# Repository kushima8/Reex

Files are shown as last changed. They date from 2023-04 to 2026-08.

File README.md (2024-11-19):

# Reex
Modular Split keyboards  
  





# Build Guide

## Reex56
[ビルドガイド（日本語）](Reex56/Documents/reex56_buildguide.md)  
https://cyberdeckarsenal.booth.pm/items/4951435  
https://shop.yushakobo.jp/products/7793  

## Reex67
[ビルドガイド（日本語）](Reex67/Documents/reex67_buildguide.md)  
https://cyberdeckarsenal.booth.pm/items/4951447  
https://shop.yushakobo.jp/products/7930  

## ReexMod
[ビルドガイド（日本語）](Mod/reexmod_buildguide.md)  
https://cyberdeckarsenal.booth.pm/items/5617509  
https://cyberdeckarsenal.booth.pm/items/4773963  

## Reex56Mod (Reex56 + ReexMod)
https://shop.yushakobo.jp/products/9454  

## Reex67Mod (Reex67 + ReexMod)
https://shop.yushakobo.jp/products/9455  

## Trackball Module ＆ Case
https://github.com/kushima8/PMW3360

120px-Cc-by-nc-sa_icon svg

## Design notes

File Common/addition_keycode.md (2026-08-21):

# Reex 追加キーコード一覧
 
Reexで使用できる独自キーコードの一覧です。  
RemapまたはVIAでキーに割り当ててご使用ください。  
  
## トラックボール
 
### 設定の保存・リセット
 
| キーコード | 説明 |
|---|---|
| `REC_RST` | センサー設定[^1]をリセット |
| `REC_SAVE` | 現在のセンサー設定[^1]をEEPROMに保存 |
 
### CPI（カーソル速度）
 
| キーコード | 説明 |
|---|---|
| `CPI_I100` | CPIを100増加（最大3500） |
| `CPI_D100` | CPIを100減少（最小100） |
| `CPI_I1K` | CPIを1000増加（最大3500） |
| `CPI_D1K` | CPIを1000減少（最小100） |
 
### スクロール
 
| キーコード | 説明 |
|---|---|
| `SCRL_TO` | 押すたびにスクロールモードのON/OFFを切り替え |
| `SCRL_MO` | 押している間だけスクロールモード |
| `SCRL_DVI` | スクロール除数を1つ上げる（最大 D7 = 1/128、最も遅い） |
| `SCRL_DVD` | スクロール除数を1つ下げる（最小 D0 = 1/1、最も速い） |
| `SSNP_VRT` | スクロールスナップを垂直方向に固定 |
| `SSNP_HOR` | スクロールスナップを水平方向に固定 |
| `SSNP_FRE` | スクロールスナップを無効化（自由スクロール） |
 
### 自動マウスレイヤー
 
| キーコード | 説明 |
|---|---|
| `AML_TO` | 自動マウスレイヤーのON/OFFを切り替え |
| `AML_I50` | 自動マウスレイヤーのタイムアウトを50ms増加（最大1000ms） |
| `AML_D50` | 自動マウスレイヤーのタイムアウトを50ms減少（最小100ms） |

#### 動作

自動マウスレイヤーのONの状態で、トラックボールを転がすと**レイヤー3**に自動で切り替わり、操作をやめてから設定時間（初期値650ms）が経過すると元のレイヤーに戻ります。  
レイヤー3にマウスボタンやスクロールを割り当てておくことで、レイヤー切り替えキーを押さずにマウス操作ができます。  

レイヤー3では、以下のキーがトラックボールを止めた状態でもレイヤーを維持します。  
マウス操作を続けるためのキーとして扱われるためです。  

- マウスボタン（`KC_BTN1`〜`KC_BTN8`）
- `SCRL_MO`
- 修飾キー（Ctrl / Shift / Alt / GUI）

上記以外のキーを割り当てた場合、押した時点でレイヤー3が解除され、下のレイヤーのキーが入力されます（トラックボールを動かしながら押した場合はレイヤー3のキーが入力されます）。  
そのため、レイヤー3には上記のキーを割り当てることを推奨します。  

なお、キーを押した直後の約200msはトラックボールを動かしてもレイヤーが切り替わりません。  
タイピング中に手が触れてしまった際の誤動作を防ぐための仕様です。  
 
[^1]: CPI、スクロール除数、自動マウスレイヤーのON/OFF状態、および自動マウスレイヤーのタイムアウト

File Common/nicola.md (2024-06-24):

| Code(hex) | Remap上での表記 | 説明 |
|----|:---:|----|
|0x7E40|User 0|NICOLA配列 1|
|0x7E41|User 1|NICOLA配列 2|
|0x7E42|User 2|NICOLA配列 3|
|0x7E43|User 3|NICOLA配列 4|
|0x7E44|User 4|NICOLA配列 5|
|0x7E45|User 5|NICOLA配列 6|
|0x7E46|User 6|NICOLA配列 7|
|0x7E47|User 7|NICOLA配列 8|
|0x7E48|User 8|NICOLA配列 9|
|0x7E49|User 9|NICOLA配列 0|
|0x7E4A|User 10|NICOLA配列 -|
|0x7E4B|User 11|NICOLA配列 =|
|0x7E4C|User 12|NICOLA配列 \|
|0x7E4D|User 13|NICOLA配列 Q|
|0x7E4E|User 14|NICOLA配列 W|
|0x7E4F|User 15|NICOLA配列 E|
|0x7E50|User 16|NICOLA配列 R|
|0x7E51|User 17|NICOLA配列 T|
|0x7E52|User 18|NICOLA配列 Y|
|0x7E53|User 19|NICOLA配列 U|
|0x7E54|User 20|NICOLA配列 I|
|0x7E55|User 21|NICOLA配列 O|
|0x7E56|User 22|NICOLA配列 P|
|0x7E57|User 23|NICOLA配列 [|
|0x7E58|User 24|NICOLA配列 ]|
|0x7E59|User 25|NICOLA配列 A|
|0x7E5A|User 26|NICOLA配列 S|
|0x7E5B|User 27|NICOLA配列 D|
|0x7E5C|User 28|NICOLA配列 F|
|0x7E5D|User 29|NICOLA配列 G|
|0x7E5E|User 30|NICOLA配列 H|
|0x7E5F|User 31|NICOLA配列 J|
|0x7E60|Any 0x7E60|NICOLA配列 K|
|0x7E61|Any 0x7E61|NICOLA配列 L|
|0x7E62|Any 0x7E62|NICOLA配列 ;|
|0x7E63|Any 0x7E63|NICOLA配列 '|
|0x7E64|Any 0x7E64|NICOLA配列 Z|
|0x7E65|Any 0x7E65|NICOLA配列 X|
|0x7E66|Any 0x7E66|NICOLA配列 C|
|0x7E67|Any 0x7E67|NICOLA配列 V|
|0x7E68|Any 0x7E68|NICOLA配列 B|
|0x7E69|Any 0x7E69|NICOLA配列 N|
|0x7E6A|Any 0x7E6A|NICOLA配列 M|
|0x7E6B|Any 0x7E6B|NICOLA配列 ,|
|0x7E6C|Any 0x7E6C|NICOLA配列 .|
|0x7E6D|Any 0x7E6D|NICOLA配列 /|
|0x7E6E|Any 0x7E6E|NICOLA配列 親指左|
|0x7E6F|Any 0x7E6F|NICOLA配列 親指右|
|0x7E70|Any 0x7E6F|NICOLA配列レイヤーに移動|TO（）やMO（）などのレイヤー移動コマンドではなくコチラを使用
|0x7E71|Any 0x7E6F|QWERTY配列レイヤーに移動|TO（）やMO（）などのレイヤー移動コマンドではなくコチラを使用

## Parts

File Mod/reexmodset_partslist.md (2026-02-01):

# ReexModセットパーツリスト

## はじめに
こちらはBoothなどで頒布しているReexModセット用の同梱部品一覧です。  
各拡張の組み立て方法や別途必要なものに関しては下記各ビルドガイドを参照してください。  

[①５キー拡張](5keymod_buildguide.md)  
[②３キー拡張](3keymod_buildguide.md)  
[③ロータリーエンコーダ拡張](rotaryencodermod_buildguide.md)  
[④１キー拡張](1keymod_buildguide.md)  
[⑤４キー拡張](4keymod_buildguide.md)  

## 部品
|名称|数量|備考|
|----|:---:|----|
|PCB|5枚|各種拡張基盤
|3キー拡張用スペーサー|1個|ネジ穴2つの細長いもの
|5キー拡張用スペーサー|1個|ネジ穴4つの細長いもの
|ロータリーエンコーダ拡張中央上部/下部用スペーサー|2個|両端穴付きバー形状のもの
|ロータリーエンコーダ拡張下段用スペーサー|1個|両端穴付きバー形状の円柱が高いもの
|ロータリーエンコーダ拡張基盤上部用スペーサー|1個|中央に凹みがある枠形状のもの
|M2 3.5mmスペーサー(ARB-2003.5E)|4個|丸型両メネジ|
|M2 6mmスペーサー(ARB-2006E)|4個|丸型両メネジ|
|M2 7.5mmスペーサー(ARB-2007.5E)|5個|丸型両メネジ|
|M2 11mmスペーサー(ARB-20011E)|8個|丸型両メネジ|
|M2 4mmネジ|13本|
|M2 6mmネジ|4本|
|M2 10mmネジ|13本|
|Kailh PCB ソケット(Cherry MX用)|14個|
|ダイオード(1N4148W)|25個|

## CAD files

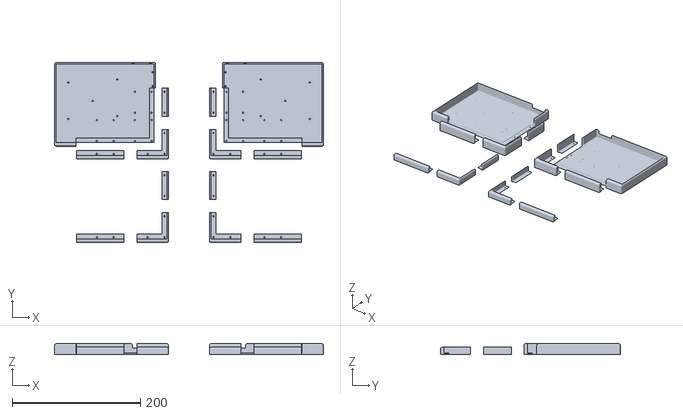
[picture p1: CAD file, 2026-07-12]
Reex56/Case/reex56_case.stl
419.6 x 280.6 x 16.5

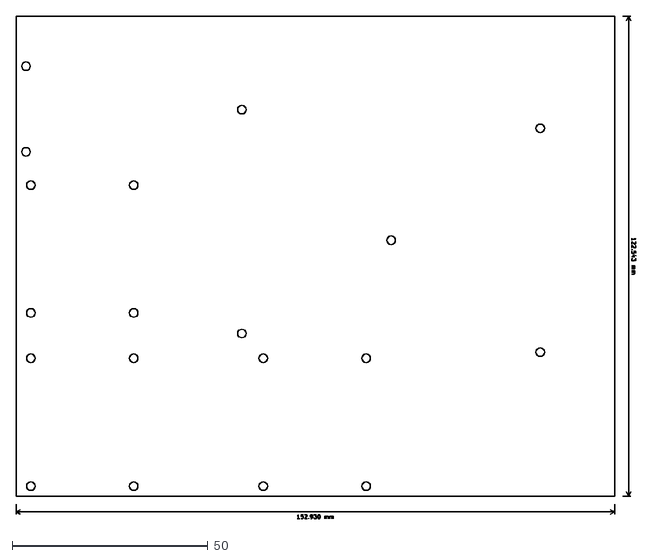
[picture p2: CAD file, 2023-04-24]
Reex56/Plate/reex56_b.dxf
158.3 x 128.3

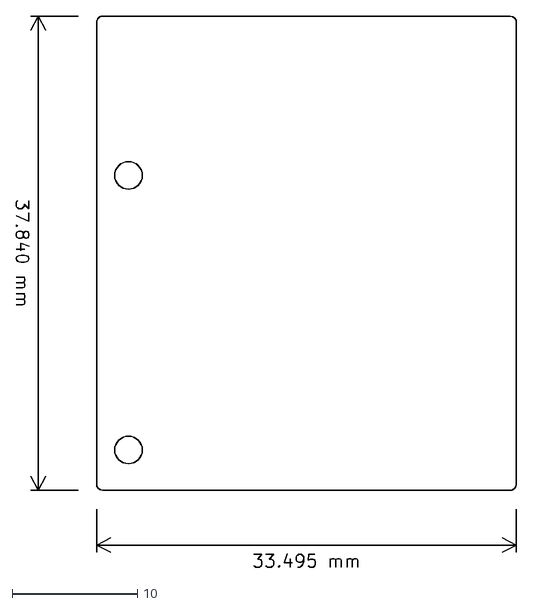
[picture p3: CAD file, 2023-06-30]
Reex67/Plate/reex_oledcover.dxf
39.9 x 44.0

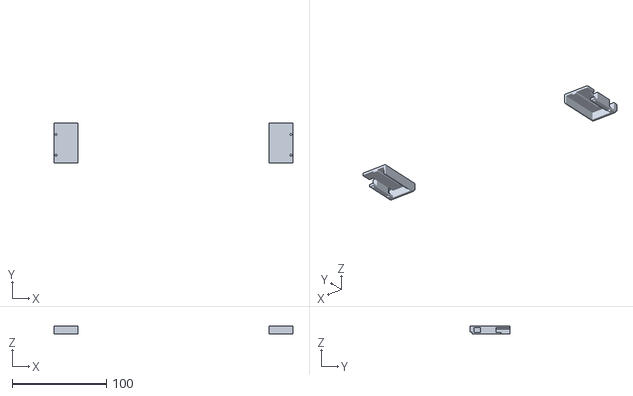
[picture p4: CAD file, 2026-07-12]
STL/reex_cover_3.5.stl
253.6 x 42.7 x 9.00

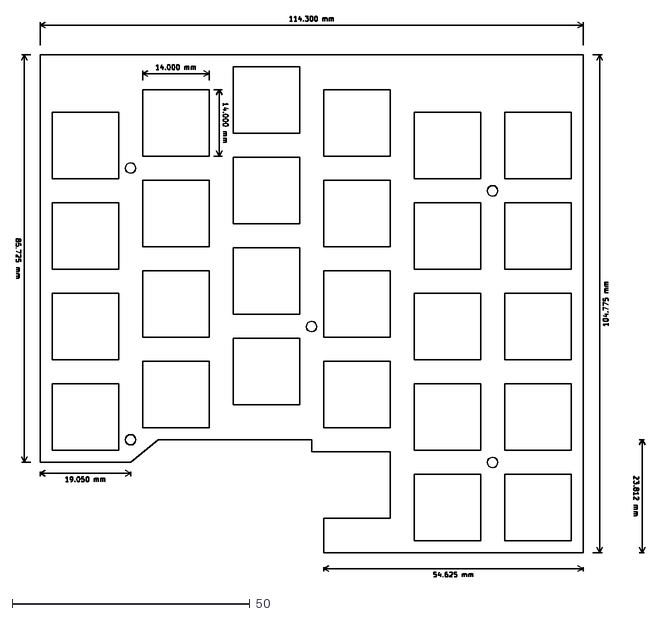
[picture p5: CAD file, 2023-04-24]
Reex56/Plate/reex56_t.dxf
132.4 x 118.1

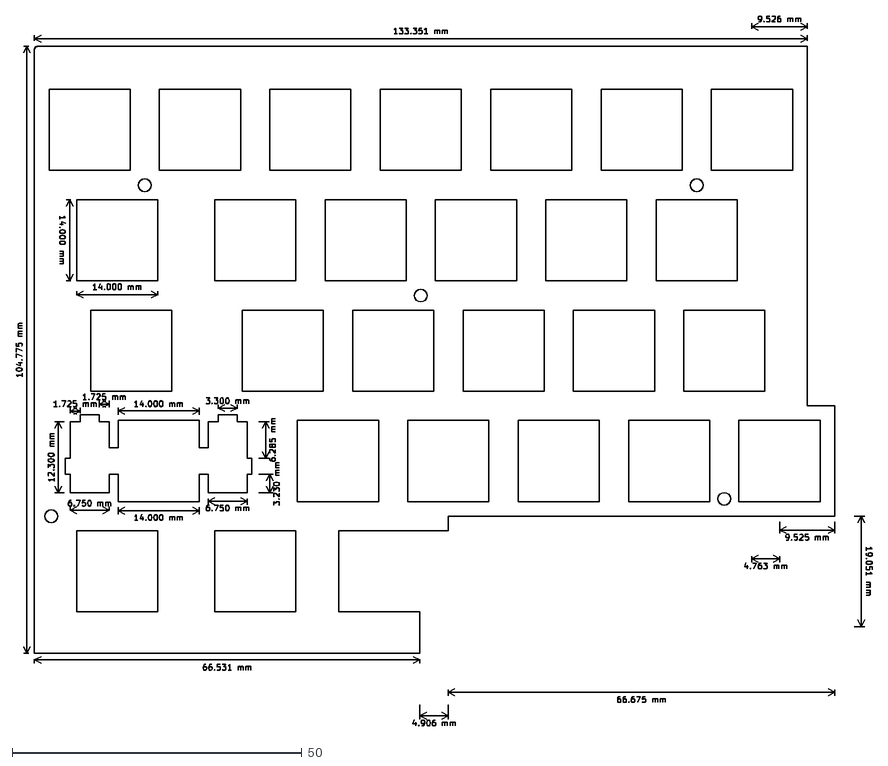
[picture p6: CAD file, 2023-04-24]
Reex67/Plate/reex67l_t.dxf
147.7 x 122.5

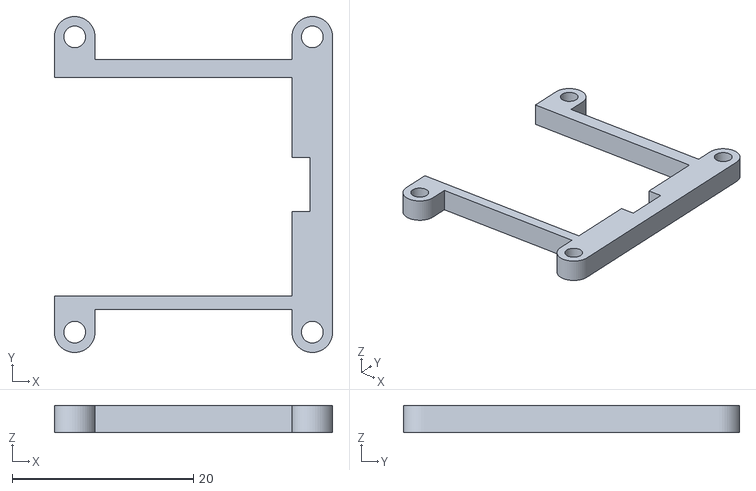
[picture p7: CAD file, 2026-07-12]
STL/reex_2.5_oneside_spacer.stl
30.7 x 37.1 x 3.00

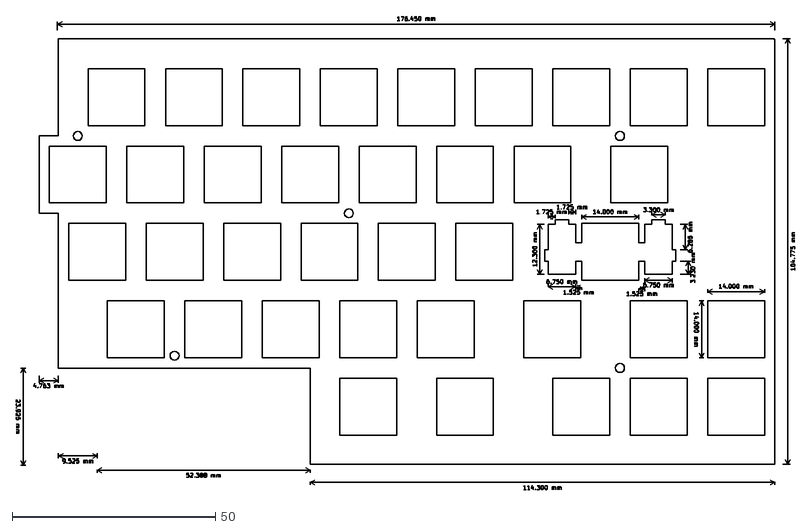
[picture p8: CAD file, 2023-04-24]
Reex67/Plate/reex67r_t.dxf
191.6 x 116.4

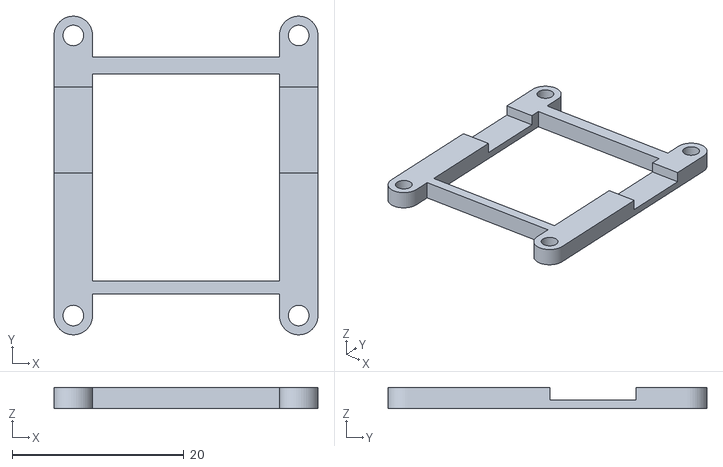
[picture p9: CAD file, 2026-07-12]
STL/reex_2.5_spacer.stl
30.7 x 37.1 x 2.50

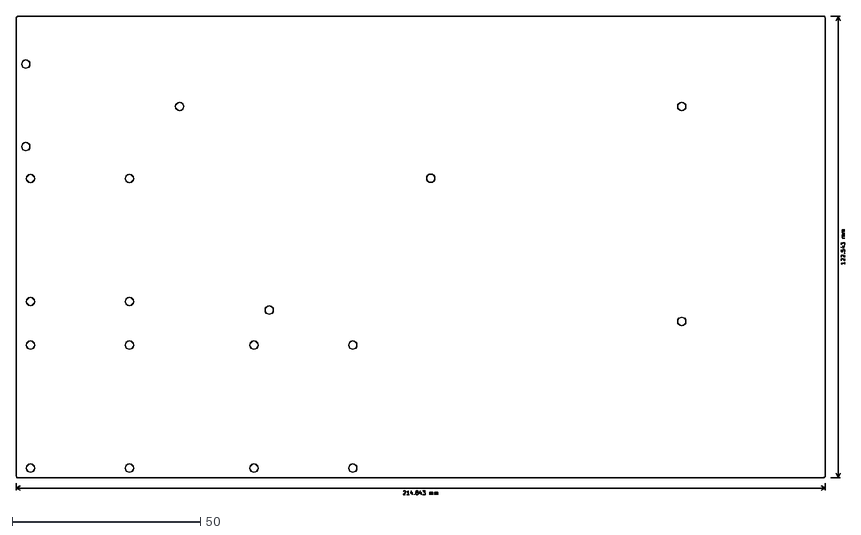
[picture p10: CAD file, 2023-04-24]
Reex67/Plate/reex67r_b.dxf
220.1 x 127.1

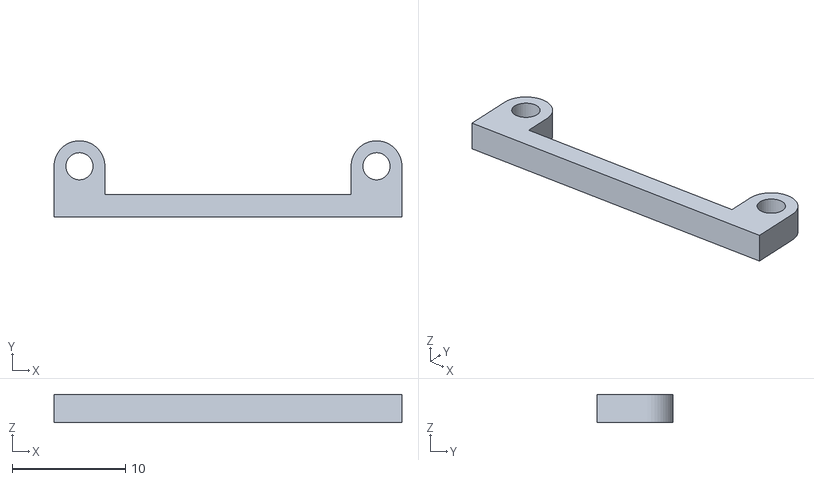
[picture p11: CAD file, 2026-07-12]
STL/reex_2.5_stick_spacer.stl
30.7 x 6.75 x 2.50

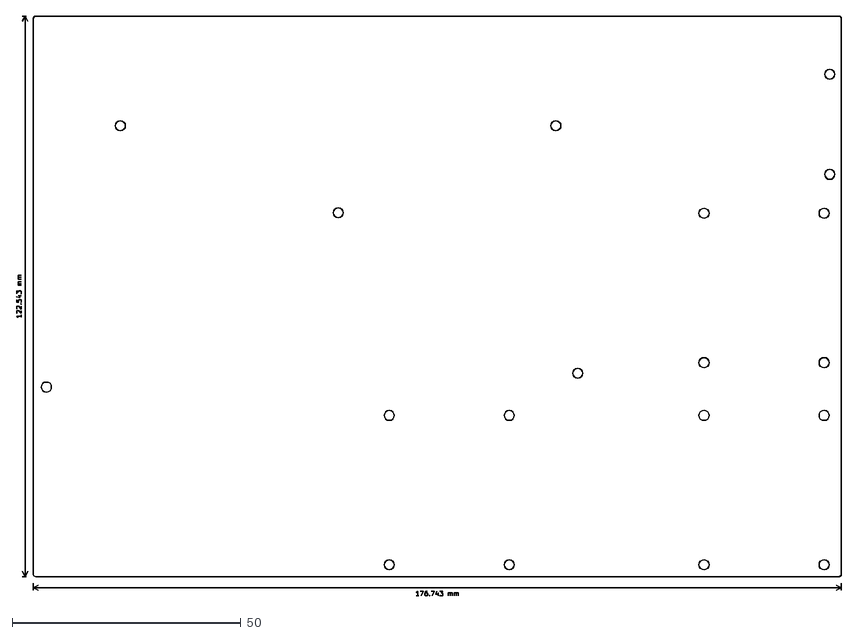
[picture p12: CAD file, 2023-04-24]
Reex67/Plate/reex67l_b.dxf
180.4 x 126.8

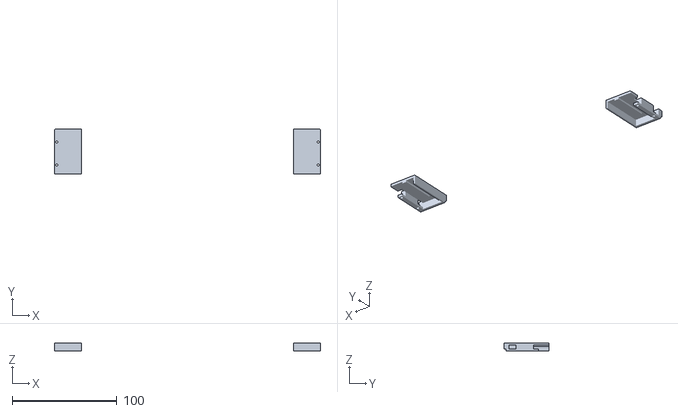
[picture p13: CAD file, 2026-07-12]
STL/reex_cover_2.5.stl
253.6 x 42.7 x 8.00

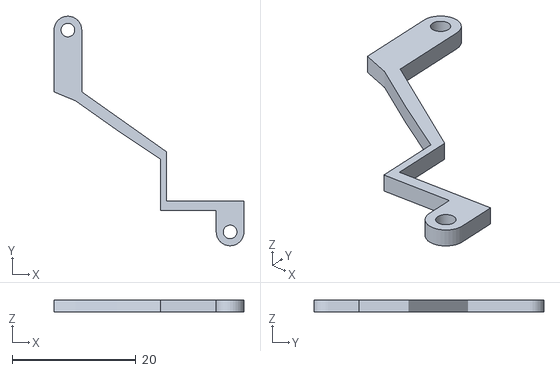
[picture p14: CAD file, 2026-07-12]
STL/reexmod_3key_spacer.stl
30.7 x 37.2 x 2.00

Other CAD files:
STL/reexmod_5key_spacer.stl
STL/reex_2.5-3.5_spacer.stl
STL/reex_cover_oled.stl
STL/reex_3.5_stick_spacer.stl

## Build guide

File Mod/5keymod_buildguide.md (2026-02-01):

# 5キー拡張 ビルドガイド

## はじめに
5キー拡張はReex56またはReex67の下記画像赤枠の位置へのみ取り付け可能です。  
※Reex67とReex56の差異はキースイッチ部分だけであり拡張取り付け部分は同一であるため、Reex67の画像は省略しております。  




キー拡張は同一側に一つのみ増設可能です。  
ロータリーエンコーダ拡張、トラックボール拡張との同一側での併用は可能です。  
（例：○ 右側 1キー拡張＋ロータリーエンコーダ拡張、左側 3キー拡張＋トラックボール拡張  
　　：✕ 右側 ロータリーエンコーダ拡張＋トラックボール拡張　左側 拡張なし   
　　：✕ 右側 拡張なし　左側  ロータリーエンコーダ拡張＋トラックボール拡張 ）  

## 部品

|名称|数量|備考|
|----|:---:|----|
|PCB|1枚|
|ボトムプレート|1枚|PCBと一体　捻って外せます|
|5キー拡張用スペーサー|1個|ネジ穴4つの細長いもの
|M2 7.5mmスペーサー(ARB-2007.5E)|3個|丸型両メネジ|
|M2 11mmスペーサー(ARB-20011E)|5個|丸型両メネジ|
|M2 4mmネジ|8本|
|M2 10mmネジ|8本|
|Kailh PCB ソケット(Cherry MX用)|5個|
|ダイオード(1N4148W)|8個|

### 別途、購入が必ず必要なもの
以下の部品は別途購入してください。

|名称|数量|備考|
|----|:---:|----|
|キースイッチ(Cherry MX互換)|5個|
|キースイッチ(Kailh Choc V1互換)|5個|Lofree Ghost switchも可|
|キーキャップ(Cherry MX互換)|5個|
|キーキャップ(Kailh Choc V1互換)|5個|
|電線|4本|
|スルーホール用テストワイヤ|4本|サンハヤト スルーホール用テストワイヤー TTW-200など|
|ゴム足|1個|

### オプション
以下の部品はオプション品です。 

|名称|数量|備考|
|----|:---:|----|
|Kailh PCB ソケット(Kailh Choc V1用)|5個|

## 組み立て
※拡張基板はリバーシブルPCBとなっております。  
　使用する位置とキーキャップの大きさにより実装面が変わります。  
　適宜説明内容を読み替えてご覧ください。 

* 1.7Pinコンスルー加工と差し替え
  * Reex基盤本体とトラックボール用センサーボードの接続に用いている8Pinコンスルーをニッパーなどを使い7Pinコンスルーに加工します。  
  * 8Pinコンスルーの右から三番目のPinをニッパーなどで切除してください。
  
  
  * Reex基盤本体の接続部分の右から三番目のPin（F6）に7PinコンスルーのPinが無くなっている部分が来るようにセンサボードと接続するようにしてください。
  
  
* 2.ファームウェアの書き込み
  * [reex56mod_default.hex](https://github.com/kushima8/Reex/tree/main/Reex56/HEX/mod/reex56mod_default.hex) or [reex67mod_default.hex](https://github.com/kushima8/Reex/tree/main/Reex67/HEX/mod/reex56mod_default.hex)を指定してファームウェアを書き込んでください。
* 3.ダイオードのはんだ付け
  * PCB裏面のダイオード取り付け箇所の片側にあらかじめはんだを盛ります。  
  * その後、線が書いてある方を右(三角形の頂点の先に縦棒がある方)にセットします。
  * ダイオードをピンセットで持ちつつ、あらかじめはんだを盛った箇所をはんだごてで加熱して片側だけはんだ付けを行います。  
  * 片側のはんだ付けが完了後、もう片方もはんだ付けを行ってください。
* 4.Kailh PCB ソケット(Cherry MX用)/Kailh PCB ソケット(Kailh Choc V1用)のはんだ付け
  * PCB裏面のソケット取り付け箇所にあらかじめはんだを盛ります。  
  * 中央の穴に干渉しないようにソケットをPCB裏面に設置しはんだ付けを行ってください。  
* 5.本体への取り付け
  * Reex本体のボトムプレートを外します。  
  * 画像赤枠の部分に  
  　・拡張基盤  
  　・5キー拡張用スペーサー  
  　・Reex本体基盤  
  　・7.5mmスペーサー  
  となるようにセットし、上から10mmネジで固定してください。   
  その後青枠の部分に  
  　・拡張基盤  
  　・11mmスペーサー  
  となるようにセットし、上から10mmネジで固定してください。  
  ※Reex67左側の中央下部のみ取り付け箇所が異なります。  
  　赤枠ではなく橙枠と青枠ではなく緑枠に取り付けてください。  
     
  
  
* 6.疎通テスト
  * 拡張基盤とReex本体基盤をテストワイヤで繋いでください。
  * TTW-200であればスルーホールに差し込むだけで接続できます。
  * 接続箇所は拡張基盤の印字とReex本体基盤の拡張取り付け部位近くにある印字が合うようにしてください。
  * Reex本体基盤の複数同じ印字がありますが、どちらに刺しても問題ありません。
  * 配線に関しては下記が画像を参考にしてください。
     
  
  
  * 接続後、キースイッチを取り付け入力可能かテストを行ってください。
  * 問題なければボトムプレートを配置し、4mmネジで固定してください。
* 7.電線のはんだ付け
  * この工程を行うと拡張基盤の取り外しが困難になります。
  * テストワイヤで接続した状態で、十分操作感などを確かめ変更の余地がないと確認後、この工程に進むようにしてください。
  * テストワイヤを外し電線と入れ替えるような形で拡張基板と本体基盤にはんだ付けを行い接続してください。

組み立ての手順は、以上です。

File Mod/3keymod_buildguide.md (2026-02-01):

# 3キー拡張 ビルドガイド

## はじめに
3キー拡張はReex56またはReex67の下記画像赤枠の位置へのみ取り付け可能です。  
※Reex67とReex56の差異はキースイッチ部分だけであり拡張取り付け部分は同一であるため、Reex67の画像は省略しております。  
  



キー拡張は同一側に一つのみ増設可能です。  
ロータリーエンコーダ拡張、トラックボール拡張との同一側での併用は可能です。  
（例：○ 右側 1キー拡張＋ロータリーエンコーダ拡張、左側 3キー拡張＋トラックボール拡張  
　　：✕ 右側 ロータリーエンコーダ拡張＋トラックボール拡張　左側 拡張なし   
　　：✕ 右側 拡張なし　左側  ロータリーエンコーダ拡張＋トラックボール拡張 ）  

## 部品

|名称|数量|備考|
|----|:---:|----|
|PCB|1枚|
|ボトムプレート|1枚|PCBと一体　捻って外せます|
|3キー拡張用スペーサー|1個|ネジ穴2つの細長いもの
|M2 7.5mmスペーサー(ARB-2007.5E)|2個|丸型両メネジ|
|M2 11mmスペーサー(ARB-20011E)|3個|丸型両メネジ|
|M2 4mmネジ|5本|
|M2 10mmネジ|5本|
|Kailh PCB ソケット(Cherry MX用)|3個|
|ダイオード(1N4148W)|5個|

### 別途、購入が必ず必要なもの
以下の部品は別途購入してください。

|名称|数量|備考|
|----|:---:|----|
|キースイッチ(Cherry MX互換)|3個|
|キースイッチ(Kailh Choc V1互換)|3個|Lofree Ghost switchも可|
|キーキャップ(Cherry MX互換)|3個|
|キーキャップ(Kailh Choc V1互換)|3個|
|電線|4本|
|スルーホール用テストワイヤ|4本|サンハヤト スルーホール用テストワイヤー TTW-200など|
|ゴム足|1個|

### オプション
以下の部品はオプション品です。 

|名称|数量|備考|
|----|:---:|----|
|Kailh PCB ソケット(Kailh Choc V1用)|3個|

## 組み立て
※拡張基板はリバーシブルPCBとなっております。  
　使用する位置とキーキャップの大きさにより実装面が変わります。  
　適宜説明内容を読み替えてご覧ください。  

* 1.7Pinコンスルー加工と差し替え
  * Reex基盤本体とトラックボール用センサーボードの接続に用いている8Pinコンスルーをニッパーなどを使い7Pinコンスルーに加工します。  
  * 8Pinコンスルーの右から三番目のPinをニッパーなどで切除してください。
  
  
  * Reex基盤本体の接続部分の右から三番目のPin（F6）に7PinコンスルーのPinが無くなっている部分が来るようにセンサボードと接続するようにしてください。
  
  
* 2.ファームウェアの書き込み
  * [reex56mod_default.hex](https://github.com/kushima8/Reex/tree/main/Reex56/HEX/mod/reex56mod_default.hex) or [reex67mod_default.hex](https://github.com/kushima8/Reex/tree/main/Reex67/HEX/mod/reex56mod_default.hex)を指定してファームウェアを書き込んでください。
* 3.ダイオードのはんだ付け
  * PCB裏面のダイオード取り付け箇所の片側にあらかじめはんだを盛ります。  
  * その後、線が書いてある方を右(三角形の頂点の先に縦棒がある方)にセットします。
  * ダイオードをピンセットで持ちつつ、あらかじめはんだを盛った箇所をはんだごてで加熱して片側だけはんだ付けを行います。  
  * 片側のはんだ付けが完了後、もう片方もはんだ付けを行ってください。
* 4.Kailh PCB ソケット(Cherry MX用)/Kailh PCB ソケット(Kailh Choc V1用)のはんだ付け
  * PCB裏面のソケット取り付け箇所にあらかじめはんだを盛ります。  
  * 中央の穴に干渉しないようにソケットをPCB裏面に設置しはんだ付けを行ってください。  
* 5.本体への取り付け
  * Reex本体のボトムプレートを外します。  
  * 画像赤枠の部分に  
  　・拡張基盤  
  　・3キー拡張用スペーサー
  　・Reex本体基盤  
  　・7.5mmスペーサー  
  となるようにセットし、上から10mmネジで固定してください。  
  その後青枠の部分に  
  　・拡張基盤  
  　・11mmスペーサー  
  となるようにセットし、上から10mmネジで固定してください。  
     
  
  
* 6.疎通テスト
  * 拡張基盤とReex本体基盤をテストワイヤで繋いでください。
  * TTW-200であればスルーホールに差し込むだけで接続できます。
  * 接続箇所は拡張基盤の印字とReex本体基盤の拡張取り付け部位近くにある印字が合うようにしてください。
  * Reex本体基盤の複数同じ印字がありますが、どちらに刺しても問題ありません。
  * 配線に関しては下記が画像を参考にしてください。
     
  
  
  * 接続後、キースイッチを取り付け入力可能かテストを行ってください。
  * 問題なければボトムプレートを配置し、4mmネジで固定してください。
* 7.電線のはんだ付け
  * この工程を行うと拡張基盤の取り外しが困難になります。
  * テストワイヤで接続した状態で、十分操作感などを確かめ変更の余地がないと確認後、この工程に進むようにしてください。
  * テストワイヤを外し電線と入れ替えるような形で拡張基板と本体基盤にはんだ付けを行い接続してください。

組み立ての手順は、以上です。

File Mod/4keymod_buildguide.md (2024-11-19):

# 4キー拡張 ビルドガイド

## はじめに
4キー拡張はReex56またはReex67の下記画像赤枠の位置へのみ取り付け可能です。  
※Reex67とReex56の差異はキースイッチ部分だけであり拡張取り付け部分は同一であるため、Reex67の画像は省略しております。  
  


キー拡張は同一側に一つのみ増設可能です。  
ロータリーエンコーダ拡張、トラックボール拡張との同一側での併用は可能です。  
（例：○ 右側 1キー拡張＋ロータリーエンコーダ拡張、左側 3キー拡張＋トラックボール拡張  
　　：✕ 右側 ロータリーエンコーダ拡張＋トラックボール拡張　左側 拡張なし   
　　：✕ 右側 拡張なし　左側  ロータリーエンコーダ拡張＋トラックボール拡張 ）  

## 部品

|名称|数量|備考|
|----|:---:|----|
|PCB|1枚|
|ボトムプレート|1枚|PCBと一体　捻って外せます|
|M2 6mmスペーサー(ARB-2006E)|4個|丸型両メネジ|
|M2 4mmネジ|4本|
|M2 6mmネジ|4本|
|Kailh PCB ソケット(Cherry MX用)|4個|
|ダイオード(1N4148W)|7個|

### 別途、購入が必ず必要なもの
以下の部品は別途購入してください。

|名称|数量|備考|
|----|:---:|----|
|キースイッチ(Cherry MX互換)|4個|
|キースイッチ(Kailh Choc V1互換)|4個|Lofree Ghost switchも可|
|キーキャップ(Cherry MX互換)|4個|
|キーキャップ(Kailh Choc V1互換)|4個|
|電線|3本|
|スルーホール用テストワイヤ|3本|サンハヤト スルーホール用テストワイヤー TTW-200など|
|ゴム足|2個|

### オプション
以下の部品はオプション品です。 

|名称|数量|備考|
|----|:---:|----|
|Kailh PCB ソケット(Kailh Choc V1用)|4個|

## 組み立て

* 1.7Pinコンスルー加工と差し替え
  * Reex基盤本体とトラックボール用センサーボードの接続に用いている8Pinコンスルーをニッパーなどを使い7Pinコンスルーに加工します。  
  * 8Pinコンスルーの右から三番目のPinをニッパーなどで切除してください。
  
  
  * Reex基盤本体の接続部分の右から三番目のPin（F6）に7PinコンスルーのPinが無くなっている部分が来るようにセンサボードと接続するようにしてください。
  
  
* 2.ファームウェアの書き込み
  * [reex56mod_default.hex](https://github.com/kushima8/Reex/tree/main/Reex56/HEX/mod/reex56mod_default.hex) or [reex67mod_default.hex](https://github.com/kushima8/Reex/tree/main/Reex67/HEX/mod/reex56mod_default.hex)を指定してファームウェアを書き込んでください。
* 3.ダイオードのはんだ付け
  * PCB裏面のダイオード取り付け箇所の片側にあらかじめはんだを盛ります。  
  * その後、線が書いてある方を右(三角形の頂点の先に縦棒がある方)にセットします。
  * ダイオードをピンセットで持ちつつ、あらかじめはんだを盛った箇所をはんだごてで加熱して片側だけはんだ付けを行います。  
  * 片側のはんだ付けが完了後、もう片方もはんだ付けを行ってください。
* 4.Kailh PCB ソケット(Cherry MX用)/Kailh PCB ソケット(Kailh Choc V1用)のはんだ付け
  * PCB裏面のソケット取り付け箇所にあらかじめはんだを盛ります。  
  * 中央の穴に干渉しないようにソケットをPCB裏面に設置しはんだ付けを行ってください。  
* 5.本体への取り付け
  * Reex本体のボトムプレートを外します。  
  * 画像赤枠の部分に  
  　・Reex本体基盤  
  　・拡張基盤  
  　・6mmスペーサー  
  となるようにセットし、上から6mmネジで固定してください。  
    
  
  
  その後拡張基盤下部に  
  　・拡張基盤  
  　・6mmスペーサー  
  となるようにセットし、上から6mmネジで固定してください。  
* 6.疎通テスト
  * 拡張基盤とReex本体基盤をテストワイヤで繋いでください。
  * TTW-200であればスルーホールに差し込むだけで接続できます。
  * 接続箇所は拡張基盤の印字とReex本体基盤の拡張取り付け部位近くにある印字が合うようにしてください。
  * Reex本体基盤の複数同じ印字がありますが、どちらに刺しても問題ありません。
  * 配線に関しては下記が画像を参考にしてください。  
    
  
  
  * 接続後、キースイッチを取り付け入力可能かテストを行ってください。
  * 問題なければボトムプレートを配置し、4mmネジで固定してください。
* 7.電線のはんだ付け
  * この工程を行うと拡張基盤の取り外しが困難になります。
  * テストワイヤで接続した状態で、十分操作感などを確かめ変更の余地がないと確認後、この工程に進むようにしてください。
  * テストワイヤを外し電線と入れ替えるような形で拡張基板と本体基盤にはんだ付けを行い接続してください。

組み立ての手順は、以上です。

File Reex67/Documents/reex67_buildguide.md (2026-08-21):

# Reex67 ビルドガイド

## ご購入前にお読みください

本製品をご購入いただいた時点で、下記「譲渡・再販について」の内容にご同意いただいたものとみなします。

### 譲渡・再販について

BOOTHや遊舎工房など、作者本人が販売または委託している場所以外で購入された場合、同梱品の不足や不良品への対応など、各種サポートをいたしかねます。  
そのため、以下のとおりお願いしております。

1. 本製品（完成品・未完成品・付属部品を問わず）を、ネットオークション、フリマサービス、その他の方法により第三者へ有償で譲渡することを禁止します。
2. 本項に反する行為を確認した場合、以後の販売をお断りする場合があります。

## はじめに


このたびはご購入いただきありがとうございます。  
本製品は組み立てが必要なキットです。  

作成にあたり不明点や疑問点などがありましたら、作者の[Twitterアカウント](https://twitter.com/kushima8)までご連絡ください。  
Twitter以外で連絡を頂いても対応が厳しいです。  
FF外からのリプライは通知オフにしており気づかない場合がこざいますご了承ください。  
それとDiscordのコミュニティなどで作者以外の方だけに不明点や疑問点などを質問することは非推奨です。  

Reex67は各種ブレークアウトボードを接続して拡張することを主眼に開発したモジュラー式キーボードです。  
使用するキーキャップについては[キーレイアウト](https://www.keyboard-layout-editor.com/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'&_w:2.25%3B&=Enter%3B&@_w:2.25%3B&=Shift&=Z&=X&=C&=V&=B&_x:3.75%3B&=N&=M&=%3C%0A,&=%3E%0A.&=%3F%0A%2F%2F&_w:1.75%3B&=Shift&=%E2%86%91&=Fn%3B&@_w:1.5%3B&=Ctrl&=Fn&_w:1.25%3B&=GUI&_x:2&w:1.5%3B&=Space&_x:3&w:1.25%3B&=Space&_x:2.25&w:1.5%3B&=GUI&=ALT&_x:0.5%3B&=%E2%86%90&=%E2%86%93&=%E2%86%92)を確認してください。  

写真は作成見本であり商品内容と同一ではありません。  
また仕様は予告なく変更されることがあります。  

完成品、未完成品にかかわらずヤフオク!やメルカリなどのネットオークションやフリマなどでの販売、転売は禁止しております。  
Boothや遊舎工房など作者本人が販売または委託している箇所以外で購入された場合、同梱品の不足や不良品の対応などの各種サポートが厳しいためです。  
もし発見した場合は対応します。  
ご理解のほどよろしくお願いいたします。  

ファームウェアに[qmk_firmware](https://github.com/qmk/qmk_firmware)を採用しています。  
QMKにReex67のコードはまだマージされていませんのでこの[ブランチ](https://github.com/kushima8/qmk_firmware/tree/reex)を使用してください。  

キット作成前にPro Microの書き込み環境の構築を行ってください。  
ファームウェアの書き込み環境の構築については下記のサリチル酸さんのサイトを参考にしてください。  
[（初心者編）自作キーボードにファームウェアを書き込む](https://salicylic-acid3.hatenablog.com/entry/qmk-toolbox)  

キー割り当ての変更方法などはご自身でお調べいただくようお願いします。  

GUIから簡単にキー割り当てを変更できる[VIA](https://caniusevia.com/)と[Remap](https://remap-keys.app/)に対応しております。  
各種キー割り当ても含めLEDの光度などの設定できますのでご活用ください。  
VIAとRemapについては下記のサリチル酸さんのサイトを参考にしてください。  
[（初心者編）VIAを使ってキーマップを書き換えよう](https://salicylic-acid3.hatenablog.com/entry/via-manual)  
[（初心者編）Remapを使ってキーマップを書き換えよう](https://salicylic-acid3.hatenablog.com/entry/remap-manual)  

[プレートデータ](https://github.com/kushima8/Reex/tree/main/Reex67/Plate)データを公開しています。  
アルミプレートなど作成したい場合にお使いください。  

[センサブレイクアウトボート](https://github.com/kushima8/PMW3360)に関してもケース含めデータを公開しています。  
ご自由にお使いください。  

以下の部品リストを参考に欠品がないか確認をお願いします。  
欠品や不良品などがありましたら確認したのちに対応いたします。  
ただし、海外など発送が難しい場合はこちらの指定する方法での一部返金などで対応します。  
あらかじめご了承ください。  

## 部品

### キットに付属しているもの

|名称|数量|備考|
|----|:---:|----|
|PCB|2枚|右側用、左側用各1枚ずつ|
|トッププレート|2枚|右側用、左側用各1枚ずつ|
|ボトムプレート|2枚|右側用、左側用各1枚ずつ|
|スペースキー用トッププレート|2枚||
|中央上部/下部用スペーサー|1個||枠形状のもの
|下段用スペーサー|1個|片側の円柱が高い枠形状のもの|
|M2 3mmスペーサー(ARB-2003E)|10個|丸型両メネジ|
|M2 3.5mmスペーサー(ARB-2003.5E)|4個|丸型両メネジ|
|M2 7.5mmスペーサー(ARB-2007.5E)|10個|丸型両メネジ|
|M2 4mmネジ|14本|
|M2 10mmネジ|14本|
|Kailh PCB ソケット(MX用)|69個|
|ダイオード(1N4148W)|86個|
|タクトスイッチ|2個|
|TRRSジャック(MJ-4PP-9)|2個|
|PMW3360DM-T2QU|1個|レンズ付き|
|PMW3360ブレイクアウトボード|1枚|
|34mm版トラックボールケース|1個|ローマウント版|
|25mm版トラックボールケースカバー(右側用) |1個||
|25mm版トラックボールケースカバー(左側用） |1個||
|ステンレスミニアチュアベアリング(3×6×2.5mm)|3個|
|六角ナット(M3 厚さ2.4mm)|3個|
|(+)ナベ頭小ねじ(M3 10mm)|3個|
|コンスルーピンヘッダ(2.5mm 8PIN)|1個|
|ゴム足|8個|

### 別途、購入が必ず必要なもの
以下の部品は別途購入してください。

|名称|数量|備考|
|----|:---:|----|
|キースイッチ(Cherry MX互換)|67個|
|キーキャップ(Cherry MX互換)|67個|
|Pro Micro|2個|※|
|コンスルーピンヘッダ(2.5mm 12PIN)|4個|
|TRRSケーブル|1本|
|トラックボール(34mm)|1個|
|2Uスタビライザー(Cherry MX互換)|2個|

※動作確認しているPro Microは以下の通りになります。  
　下記以外のPro Microを使用する場合は動作しないことがあります。  
　使用する場合はご自身で調整してください。  
　Pro Micro（単体）黒基盤/青基盤  
　https://shop.yushakobo.jp/products/pro-micro?variant=42225070768359

### オプション
以下の部品はオプション品です。  
キーボードを光らせたいなどの場合のみ別途購入してください。  

|名称|数量|備考|
|----|:---:|----|
|LEDチップ(YS-SK6812MINI-E)|75個|
|OLEDモジュール|2個|
|OLED用ピンソケット|2個|

※一部画像に制作手順が似ているReex56の画像を使用しております。

## 組み立て
* 表面  
  
* 裏面  
  
* 1.ヤスリがけ
  * 製造の都合上PCBにバリが存在します。  
  
  * 赤丸の箇所を市販されている紙ヤスリなどで研磨してください。
* 2.Pro Microのはんだ付け
  * チップが載っている面が内側になるようにし、コンスルーピンヘッダを取り付けはんだ付けをしてください。
  * コンスルーピンヘッダには取り付け方向があるため気をつけてください。
  * [コンスルー - Self-Made Keyboards in Japan - ](https://scrapbox.io/self-made-kbds-ja/%E3%82%B3%E3%83%B3%E3%82%B9%E3%83%AB%E3%83%BC)  
  
* 3.ファームウェアの書き込み
  * [reex67_test.hex](https://github.com/kushima8/Reex/tree/main/Reex67/HEX/reex67_test.hex)を指定してファームウェアを書き込んでください。
* 4.センサーのはんだ付け
  * ブレイクアウトボードの既にICがはんだ付けされている⾯を表にし、4PINが2列になっている方を左側してください。
  * センサーチップの⽂字が書かれている⽅を下にしてブレイクアウトボードにセットしたあと、裏面からはんだ付けをしてください。
  * はんだ付けが終わったらセンサに貼られているシールを剥がしてください。  
 
  * レンズのガイドポストを変形させることで、レンズをセンサに固定できます。  
  * 固定する場合は一度本機を完成させトラックボールが動くことを確認したのち、レンズをセンサにキッチリはめ込んだ状態ではんだごてなどを使い画像赤丸部分のガイドポストをセンサに触れないように溶かし変形させ固定してください。  
  * 高温すぎるとガイドポスト溶けすぎてしまうので、はんだごでなのでネジを熱し、熱したネジをガイドポストに押し付けるなどで変形させるとうまくいきます。  
 
* 5.トラックボールケースの作成  
  * 本キットでは34mm版ケースと25mm版ケースを同梱しております。  
  * 組み立て組み込み方はどちらも同じ手順で可能です。  
  * ご自身でお好きなものを選んで組み込んでください。  
  * [ケースデータ](https://github.com/kushima8/PMW3360/tree/main/stl)は公開中ですのでご自由にお使いください。
    
  * ケースは突起が突き出ているほうが表側であり、突起が2つある⽅が上、突起が1つの方が下となります。  
  * 初めに上側のネジ⽳にM2 10mmネジを⼀つづ⼊れます  
  * その後ベアリングを取り付けたM3 10mmネジを突起の穴ねじ込みます。  
  * 入れる方向などは下記画像を参考にしてください。  
  * 設置後、六角ナットで固定。  
  * 固定する際突起部分とベアリング部分を完全に密着せず若干ながら隙間を作るようにしてください。  
  * 密着しすぎるとベアリングがうまく回らない場合があります。  
    
  * 一旦この状態でトラックボールを置き、干渉の確認をしてください。  
  * ケース本体は3Dプリンタで製造しており、個体差によっては玉と爪が干渉する場合があります。  
  * 干渉する場合、、干渉しない用にヤスリなどで加工してください。  
* 6.LEDチップのはんだ付け(オプション)
  * 高い温度ではんだ付けを行うとLED破損の可能性がありますので、約270℃に設定してはんだ付けをするようにしてください。
  * 基板裏面のL字のシルクのマークの位置にLEDの足が欠けている箇所が来るように設置し、はんだ付けを行ってください。
  * はんだ付けが完了したら一度Pro Microを取り付け、LEDが光るかどうかテストを行ってください。  
  
* 7.ダイオードのはんだ付け
  * PCB裏面のダイオード取り付け箇所の片側にあらかじめはんだを盛ります。  
  
  * その後、線が書いてある方を右(三角形の頂点の先に縦棒がある方)にセットします。
  * ダイオードをピンセットで持ちつつ、あらかじめはんだを盛った箇所をはんだごてで加熱して片側だけはんだ付けを行います。  
  
  * 片側のはんだ付けが完了後、もう片方もはんだ付けを行ってください。
* 8.Kailh PCB ソケット(MX用)のはんだ付け
  * PCB裏面のソケット取り付け箇所にあらかじめはんだを盛ります。  
  
  * 中央の穴に干渉しないようにソケットをPCB裏面に設置しはんだ付けを行ってください。  
  
* 9.タクトスイッチはんだ付け
  * PCB表面から取り付け、裏面からはんだ付けを行ってください。
* 10.TRRSジャックのはんだ付け
  * PCB表面から取り付け、裏面からはんだ付けを行ってください。
* 11.OLEDの取り付け(オプション)
  * OLEDモジュールとピンヘッダのハンダ付けを行ってください。
  * ピンソケットをPCB表面から取り付け、裏面からはんだ付けを行ってください。
* 12.トラックボールユニットの取り付け  
  * トラックボールユニットは画像赤丸の六箇所から選択が可能です。  
    
  * 中央上部と中央下部の場合は12.1を、下段の場合は12.2を参考に取り付けてください。  
    * 12.1 中央上部と中央下部取り付け  
    * ケース下側のネジ⽳にM2 10mmネジを⼀つづ⼊れてください。  
    * PCB上面にケースを配置してください。  
      
    * PCB裏側からコンスルーを取り付け、ネジに中央上部/下部用スペーサーを取り付けてください。  
      
    * その後ブレイクアウトボードを取り付け、M2 3.5mmスペーサーを設置してください。  
      
    * 12.2 下段取り付け  
    * ケース下側のネジ⽳にM2 10mmネジを⼀つづ⼊れてください。  
    * PCB上面にケースを配置してください。  
    * PCB裏側からコンスルーを取り付け、ネジに下部用スペーサーを通してください。  
      
    * その後ブレイクアウトボードを取り付け、M2 3.5mmスペーサーを設置してください。  
      
* 13.キースイッチの取り付け
  * トッププレートの穴にキースイッチを取り付けてください。  
  
* 14.トッププレートの取り付け
  * トッププレート上面のネジ穴からM2 10mmネジを通し、M2 3mmスペーサーで固定してください。
  * PCBとネジ穴とキースイッチが合うようにトッププレートをPCB表面に設置。
  * 設置後、PCB裏面に飛び出たネジにM2 7.5mmスペーサーを取り付けてください。  
  
* 15.ボトムプレートの取り付け。
  * スペーサーとボトムプレートのネジ穴の位置を合わせ、M2 4mmネジで固定してください。  
* 16.Pro Microの取り付け
  * Pro Microを取り付け、PCと接続しREMAPなどを用いてキースイッチの入力の確認を行ってください。
* 17.OLEDモジュールの取り付け(オプション)
  * OLEDモジュールを取り付け、PCと接続し、表示されることの確認を行ってください。
* 18.キーキャップの取り付け
  * キースイッチにキーキャップを取り付けてください。
* 19.ゴム足の取り付け
  * ボトムプレートにゴム足を取り付けください。

組み立ての手順は、以上です。

### 用意しているファームウェアについて
3種類ほどこちらにてコンパイル済みの[ファームウェア](https://github.com/kushima8/Reex/tree/main/Reex67/HEX)を用意しております。  
中身についてはこちらの[QMK](https://github.com/kushima8/qmk_firmware/tree/reex)にて確認してください。  
以下簡単な説明になります。  
独自追加キーコードに関しては[addition_keycode](https://github.com/kushima8/Reex/tree/main/Common/addition_keycode.md)にて確認してください。  
  
* reex67_default.hex
  * [VIA対応(Remap)](https://github.com/kushima8/Reex/tree/main/Reex67/VIA)
  * レイヤー4枚
  * １番レイヤーのみボールを一定動かすと3番レイヤー(マウスレイヤー)に自動遷移  
    ボールを停止して一定時間経過か、LCTRLと設定したマウスキーやスクロールキー以外を押下すると遷移前レイヤーに戻る
* reex67_12k.hex
  * [VIA対応(Remap)](https://github.com/kushima8/Reex/tree/main/Reex56/VIA)
  * レイヤー4枚
  * １番レイヤーのみボールを一定動かすと3番レイヤー(マウスレイヤー)に自動遷移  
    ボールを停止して一定時間経過か、LCTRLと設定したマウスキーやスクロールキー以外を押下すると遷移前レイヤーに戻る
  * MAXCPI 12000（他ファームウェアはMAPCPI 3500）
  * ワンショットキー機能、タッピング機能無効
* reex67_test.hex
  * 動作確認用
  * [VIA対応(Remap)](https://github.com/kushima8/Reex/tree/main/Reex67/VIA)
  * レイヤー1枚

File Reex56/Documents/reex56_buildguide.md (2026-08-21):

# Reex56 ビルドガイド

## ご購入前にお読みください

本製品をご購入いただいた時点で、下記「譲渡・再販について」の内容にご同意いただいたものとみなします。

### 譲渡・再販について

BOOTHや遊舎工房など、作者本人が販売または委託している場所以外で購入された場合、同梱品の不足や不良品への対応など、各種サポートをいたしかねます。  
そのため、以下のとおりお願いしております。

1. 本製品（完成品・未完成品・付属部品を問わず）を、ネットオークション、フリマサービス、その他の方法により第三者へ有償で譲渡することを禁止します。
2. 本項に反する行為を確認した場合、以後の販売をお断りする場合があります。

## はじめに


このたびはご購入いただきありがとうございます。  
本製品は組み立てが必要なキットです。  

作成にあたり不明点や疑問点などがありましたら、作者の[Twitterアカウント](https://twitter.com/kushima8)までご連絡ください。  
Twitter以外で連絡を頂いても対応が厳しいです。  
FF外からのリプライは通知オフにしており気づかない場合がこざいますご了承ください。  
それとDiscordのコミュニティなどで作者以外の方だけに不明点や疑問点などを質問することは非推奨です。  

Reex56は各種ブレークアウトボードを接続して拡張することを主眼に開発したモジュラー式キーボードです。  
使用するキーキャップについては[キーレイアウト](https://www.keyboard-layout-editor.com/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(%0A9%3B&@_y:-0.8799999999999999&x:5%3B&=%25%0A5&_x:0.75%3B&=%5E%0A6%3B&@_y:-0.875&a:7%3B&=%3B&@_y:-0.995&x:1&a:4%3B&=!%0A1&_x:8.75%3B&=)%0A0&_a:7%3B&=%3B&@_y:-0.3799999999999999&x:3&a:4%3B&=E&_x:4.75%3B&=I%3B&@_y:-0.8700000000000001&x:2%3B&=W&_x:1%3B&=R&_x:2.75%3B&=U&_x:1%3B&=O%3B&@_y:-0.8799999999999999&x:5%3B&=T&_x:0.75%3B&=Y%3B&@_y:-0.875&a:7%3B&=%3B&@_y:-0.9950000000000001&x:1&a:4%3B&=Q&_x:8.75%3B&=P&_a:7%3B&=%3B&@_y:-0.3799999999999999&x:3&a:4%3B&=D&_x:4.75%3B&=K%3B&@_y:-0.8700000000000001&x:2%3B&=S&_x:1%3B&=F&_x:2.75%3B&=J&_x:1%3B&=L%3B&@_y:-0.8799999999999999&x:5%3B&=G&_x:0.75%3B&=H%3B&@_y:-0.875&a:7%3B&=%3B&@_y:-0.9950000000000001&x:1&a:4%3B&=A&_x:8.75%3B&=%2F:%0A%2F%3B&_a:7%3B&=%3B&@_y:-0.3799999999999999&x:3&a:4%3B&=C&_x:4.75%3B&=%3C%0A,%3B&@_y:-0.8700000000000001&x:2%3B&=X&_x:1%3B&=V&_x:2.75%3B&=M&_x:1%3B&=%3E%0A.%3B&@_y:-0.8799999999999999&x:5%3B&=B&_x:0.75%3B&=N%3B&@_y:-0.875&a:7%3B&=%3B&@_y:-0.9950000000000001&x:1&a:4%3B&=Z&_x:8.75%3B&=%3F%0A%2F%2F&_a:7%3B&=%3B&@_y:-0.25&x:2%3B&=&_x:6.75%3B&=%3B&@_y:-0.75%3B&=&=&_x:8.75%3B&=&=%3B&@_rx:6.5&ry:4.25&y:0.25&x:-1.5&w:1.25%3B&=&_x:0.5&w:1.25%3B&=)を確認してください。  

写真は作成見本であり商品内容と同一ではありません。  
また仕様は予告なく変更されることがあります。  

完成品、未完成品にかかわらずヤフオク!やメルカリなどのネットオークションやフリマなどでの販売、転売は禁止しております。  
Boothや遊舎工房など作者本人が販売または委託している箇所以外で購入された場合、同梱品の不足や不良品の対応などの各種サポートが厳しいためです。  
もし発見した場合は対応します。  
ご理解のほどよろしくお願いいたします。  

ファームウェアに[qmk_firmware](https://github.com/qmk/qmk_firmware)を採用しています。  
QMKにReex56のコードはまだマージされていませんのでこの[ブランチ](https://github.com/kushima8/qmk_firmware/tree/reex)を使用してください。  

キット作成前にPro Microの書き込み環境の構築を行ってください。  
ファームウェアの書き込み環境の構築については下記のサリチル酸さんのサイトを参考にしてください。  
[（初心者編）自作キーボードにファームウェアを書き込む](https://salicylic-acid3.hatenablog.com/entry/qmk-toolbox)  

キー割り当ての変更方法などはご自身でお調べいただくようお願いします。  

GUIから簡単にキー割り当てを変更できる[VIA](https://caniusevia.com/)と[Remap](https://remap-keys.app/)に対応しております。  
各種キー割り当ても含めLEDの光度などの設定できますのでご活用ください。  
VIAとRemapについては下記のサリチル酸さんのサイトを参考にしてください。  
[（初心者編）VIAを使ってキーマップを書き換えよう](https://salicylic-acid3.hatenablog.com/entry/via-manual)  
[（初心者編）Remapを使ってキーマップを書き換えよう](https://salicylic-acid3.hatenablog.com/entry/remap-manual)  

[プレートデータ](https://github.com/kushima8/Reex/tree/main/Reex56/Plate)データを公開しています。  
アルミプレートなど作成したい場合にお使いください。  

[センサブレイクアウトボート](https://github.com/kushima8/PMW3360)に関してもケース含めデータを公開しています。  
ご自由にお使いください。  

以下の部品リストを参考に欠品がないか確認をお願いします。  
欠品や不良品などがありましたら確認したのちに対応いたします。  
ただし、海外など発送が難しい場合はこちらの指定する方法での一部返金などで対応します。  
あらかじめご了承ください。  

## 部品

### キットに付属しているもの

|名称|数量|備考|
|----|:---:|----|
|PCB|2枚|右側用、左側用各1枚ずつ|
|トッププレート|2枚|右側用、左側用各1枚ずつ|
|ボトムプレート|2枚|右側用、左側用各1枚ずつ|
|中央上部/下部用スペーサー|1個||枠形状のもの
|下段用スペーサー|1個|片側の円柱が高い枠形状のもの|
|M2 3mmスペーサー(ARB-2003E)|10個|丸型両メネジ|
|M2 3.5mmスペーサー(ARB-2003.5E)|4個|丸型両メネジ|
|M2 7.5mmスペーサー(ARB-2007.5E)|10個|丸型両メネジ|
|M2 4mmネジ|14本|
|M2 10mmネジ|14本|
|Kailh PCB ソケット(MX用)|58個|
|ダイオード(1N4148W)|75個|
|タクトスイッチ|2個|
|TRRSジャック(MJ-4PP-9)|2個|
|PMW3360DM-T2QU|1個|レンズ付き|
|PMW3360ブレイクアウトボード|1枚|
|34mm版トラックボールケース|1個|ローマウント版|
|25mm版トラックボールケースカバー(右側用) |1個||
|25mm版トラックボールケースカバー(左側用） |1個||
|ステンレスミニアチュアベアリング(3×6×2.5mm)|3個|
|六角ナット(M3 厚さ2.4mm)|3個|
|(+)ナベ頭小ねじ(M3 10mm)|3個|
|コンスルーピンヘッダ(2.5mm 8PIN)|1個|
|ゴム足|8個|

### 別途、購入が必ず必要なもの
以下の部品は別途購入してください。

|名称|数量|備考|
|----|:---:|----|
|キースイッチ(Cherry MX互換)|56個|
|キーキャップ(Cherry MX互換)|56個|
|Pro Micro|2個|※|
|コンスルーピンヘッダ(2.5mm 12PIN)|4個|
|TRRSケーブル|1本|
|トラックボール(34mm)|1個|

※動作確認しているPro Microは以下の通りになります。  
　下記以外のPro Microを使用する場合は動作しないことがあります。  
　使用する場合はご自身で調整してください。  
　Pro Micro（単体）黒基盤/青基盤  
　https://shop.yushakobo.jp/products/pro-micro?variant=42225070768359

### オプション
以下の部品はオプション品です。  
キーボードを光らせたいなどの場合のみ別途購入してください。  

|名称|数量|備考|
|----|:---:|----|
|LEDチップ(YS-SK6812MINI-E)|64個|
|OLEDモジュール|2個|
|OLED用ピンソケット|2個|

## 組み立て
* 表面  
  
* 裏面  
  
* 1.ヤスリがけ
  * 製造の都合上PCBにバリが存在します。  
  
  * 赤丸の箇所を市販されている紙ヤスリなどで研磨してください。
* 2.Pro Microのはんだ付け
  * チップが載っている面が内側になるようにし、コンスルーピンヘッダを取り付けはんだ付けをしてください。
  * コンスルーピンヘッダには取り付け方向があるため気をつけてください。
  * [コンスルー - Self-Made Keyboards in Japan - ](https://scrapbox.io/self-made-kbds-ja/%E3%82%B3%E3%83%B3%E3%82%B9%E3%83%AB%E3%83%BC)  
  
* 3.ファームウェアの書き込み
  * [reex56_test.hex](https://github.com/kushima8/Reex/tree/main/Reex56/HEX/reex56_test.hex)を指定してファームウェアを書き込んでください。
* 4.センサのはんだ付け
  * ブレイクアウトボードの既にダイオードやICがはんだ付けされている⾯を表にし、4つのスルーホールが2列になっている方を左側してください。
  * センサチップの⽂字が書かれている⽅を下にしてブレイクアウトボードにセットしたあと、裏面からはんだ付けをしてください。
  * はんだ付けが終わったらセンサに貼られているシールを剥がしてください。  
 
  * レンズのガイドポストを変形させることで、レンズをセンサに固定できます。  
  * 固定する場合は一度本機を完成させトラックボールが動くことを確認したのち、レンズをセンサにキッチリはめ込んだ状態ではんだごてなどを使い画像赤丸部分のガイドポストをセンサに触れないように溶かし変形させ固定してください。  
  * 高温すぎるとガイドポスト溶けすぎてしまうので、はんだごでなのでネジを熱し、熱したネジをガイドポストに押し付けるなどで変形させるとうまくいきます。  
 
* 5.トラックボールケースの作成  
  * 本キットでは34mm版ケースと25mm版ケースを同梱しております。  
  * 組み立て組み込み方はどちらも同じ手順で可能です。  
  * ご自身でお好きなものを選んで組み込んでください。  
  * [ケースデータ](https://github.com/kushima8/PMW3360/tree/main/stl)は公開中ですのでご自由にお使いください。
    
  * ケースは突起が突き出ているほうが表側であり、突起が2つある⽅が上、突起が1つの方が下となります。  
  * 初めに上側のネジ⽳にM2 10mmネジを⼀つづ⼊れます  
  * その後ベアリングを取り付けたM3 10mmネジを突起の穴ねじ込みます。  
  * 入れる方向などは下記画像を参考にしてください。  
  * 設置後、六角ナットで固定。  
  * 固定する際突起部分とベアリング部分を完全に密着せず若干ながら隙間を作るようにしてください。  
  * 密着しすぎるとベアリングがうまく回らない場合があります。  
    
  * 一旦この状態でトラックボールを置き、干渉の確認をしてください。  
  * ケース本体は3Dプリンタで製造しており、個体差によっては玉と爪が干渉する場合があります。  
  * 干渉する場合、、干渉しない用にヤスリなどで加工してください。  
* 6.LEDチップのはんだ付け(オプション)
  * 高い温度ではんだ付けを行うとLED破損の可能性がありますので、約270℃に設定してはんだ付けをするようにしてください。
  * 基板裏面のL字のシルクのマークの位置にLEDの足が欠けている箇所が来るように設置し、はんだ付けを行ってください。
  * はんだ付けが完了したら一度Pro Microを取り付け、LEDが光るかどうかテストを行ってください。  
  
* 7.ダイオードのはんだ付け
  * PCB裏面のダイオード取り付け箇所の片側にあらかじめはんだを盛ります。  
  
  * その後、線が書いてある方を右(三角形の頂点の先に縦棒がある方)にセットします。
  * ダイオードをピンセットで持ちつつ、あらかじめはんだを盛った箇所をはんだごてで加熱して片側だけはんだ付けを行います。  
  
  * 片側のはんだ付けが完了後、もう片方もはんだ付けを行ってください。
* 8.Kailh PCB ソケット(MX用)のはんだ付け
  * PCB裏面のソケット取り付け箇所にあらかじめはんだを盛ります。  
  
  * 中央の穴に干渉しないようにソケットをPCB裏面に設置しはんだ付けを行ってください。  
  
* 9.タクトスイッチはんだ付け
  * PCB表面から取り付け、裏面からはんだ付けを行ってください。
* 10.TRRSジャックのはんだ付け
  * PCB表面から取り付け、裏面からはんだ付けを行ってください。
* 11.OLEDの取り付け(オプション)
  * OLEDモジュールとピンヘッダのハンダ付けを行ってください。
  * ピンソケットをPCB表面から取り付け、裏面からはんだ付けを行ってください。
* 12.トラックボールユニットの取り付け  
  * トラックボールユニットは画像赤丸の六箇所から選択が可能です。  
    
  * 中央上部と中央下部の場合は12.1を、下段の場合は12.2を参考に取り付けてください。  
    * 12.1 中央上部と中央下部取り付け  
    * ケース下側のネジ⽳にM2 10mmネジを⼀つづ⼊れてください。  
    * PCB上面にケースを配置してください。  
      
    * PCB裏側からコンスルーを取り付け、ネジに中央上部/下部用スペーサーを取り付けてください。  
      
    * その後ブレイクアウトボードを取り付け、M2 3.5mmスペーサーを設置してください。  
      
    * 12.2 下段取り付け  
    * ケース下側のネジ⽳にM2 10mmネジを⼀つづ⼊れてください。  
    * PCB上面にケースを配置してください。  
    * PCB裏側からコンスルーを取り付け、ネジに下部用スペーサーを通してください。  
      
    * その後ブレイクアウトボードを取り付け、M2 3.5mmスペーサーを設置してください。  
      
* 13.キースイッチの取り付け
  * トッププレートの穴にキースイッチを取り付けてください。  
  
* 14.トッププレートの取り付け
  * トッププレート上面のネジ穴からM2 10mmネジを通し、M2 3mmスペーサーで固定してください。
  * PCBとネジ穴とキースイッチが合うようにトッププレートをPCB表面に設置。
  * 設置後、PCB裏面に飛び出たネジにM2 7.5mmスペーサーを取り付けてください。  
  
* 15.ボトムプレートの取り付け。
  * スペーサーとボトムプレートのネジ穴の位置を合わせ、M2 4mmネジで固定してください。  
* 16.Pro Microの取り付け
  * Pro Microを取り付け、PCと接続しREMAPなどを用いてキースイッチの入力の確認を行ってください。
* 17.OLEDモジュールの取り付け(オプション)
  * OLEDモジュールを取り付け、PCと接続し、表示されることの確認を行ってください。
* 18.キーキャップの取り付け
  * キースイッチにキーキャップを取り付けてください。
* 19.ゴム足の取り付け
  * ボトムプレートにゴム足を取り付けください。

組み立ての手順は、以上です。

### 用意しているファームウェアについて
3種類ほどこちらにてコンパイル済みの[ファームウェア](https://github.com/kushima8/Reex/tree/main/Reex56/HEX)を用意しております。  
中身についてはこちらの[QMK](https://github.com/kushima8/qmk_firmware/tree/reex)にて確認してください。  
以下簡単な説明になります。  
独自追加キーコードに関しては[addition_keycode](https://github.com/kushima8/Reex/tree/main/Common/addition_keycode.md)にて確認してください。  
  
* reex56_default.hex
  * [VIA対応(Remap)](https://github.com/kushima8/Reex/tree/main/Reex56/VIA)
  * レイヤー4枚
  * 1番レイヤーのみボールを一定動かすと3番レイヤー(マウスレイヤー)に自動遷移  
    ボールを停止して一定時間経過か、LCTRLと設定したマウスキーやスクロールキー以外を押下すると遷移前レイヤーに戻る
* reex56_12k.hex
  * [VIA対応(Remap)](https://github.com/kushima8/Reex/tree/main/Reex56/VIA)
  * レイヤー4枚
  * 1番レイヤーのみボールを一定動かすと3番レイヤー(マウスレイヤー)に自動遷移  
    ボールを停止して一定時間経過か、LCTRLと設定したマウスキーやスクロールキー以外を押下すると遷移前レイヤーに戻る
  * MAXCPI 12000（他ファームウェアはMAPCPI 3500）
  * ワンショットキー機能、タッピング機能無効
* reex56_test.hex
  * 動作確認用
  * [VIA対応(Remap)](https://github.com/kushima8/Reex/tree/main/Reex56/VIA)
  * レイヤー1枚

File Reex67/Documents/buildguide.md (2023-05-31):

# Reex67 ビルドガイド
## はじめに


このたびはご購入いただきありがとうございます。<br>
本製品は組み立てが必要なキットです。<br>

Reex67は各種ブレークアウトボードを接続して拡張することを主眼に開発したモジュラー式キーボードです。<br>
使用するキーキャップについては[キーレイアウト](http://www.keyboard-layout-editor.com/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,&=%3E%0A.&=%3F%0A%2F%2F&_w:1.75%3B&=Shift&=%E2%86%91&=Fn%3B&@_w:1.5%3B&=Ctrl&=Fn&_w:1.25%3B&=GUI&_x:2&w:1.5%3B&=Space&_x:3&w:1.25%3B&=Space&_x:2.25&w:1.5%3B&=GUI&=ALT&_x:0.5%3B&=%E2%86%90&=%E2%86%93&=%E2%86%92)を確認してください。<br>

写真は作成見本であり商品内容と同一ではありません。<br>
また仕様は予告なく変更されることがあります。<br>

完成品、未完成品に関わらずヤフオク!やメルカリなどのネットオークションやフリマなどでの販売、転売は禁止しております。<br>
Boothや遊舎工房など作者本人が販売または委託している箇所以外で購入された場合、同梱品の不足や不良品の対応などの各種サポートが厳しいためです。<br>
もし発見した場合は対応します。<br>
ご理解のほどよろしくお願いいたします。<br>

ファームウェアに[qmk_firmware](https://github.com/qmk/qmk_firmware)を採用しています。<br>
QMKにReex67のコードはまだマージされていませんのでこの[ブランチ](https://github.com/kushima8/qmk_firmware/tree/reex)を使用してください。<br>

キット作成前にPro Microの書き込み環境の構築を行ってください。<br>
ファームウェアの書き込み環境の構築については下記のサリチル酸さんのサイトを参考にしてください。<br>
[（初心者編）自作キーボードにファームウェアを書き込む](https://salicylic-acid3.hatenablog.com/entry/qmk-toolbox)<br>

キー割り当ての変更方法などはご自身でお調べいただくようお願いします。<br>

GUIから簡単にキー割り当てを変更できる[VIA](https://caniusevia.com/)と[Remap](https://remap-keys.app/)に対応しております。<br>
各種キー割り当ても含めLEDの光度などの設定できますのでご活用ください。<br>
VIAとRemapについては下記のサリチル酸さんのサイトを参考にしてください。<br>
[（初心者編）VIAを使ってキーマップを書き換えよう](https://salicylic-acid3.hatenablog.com/entry/via-manual)<br>
[（初心者編）Remapを使ってキーマップを書き換えよう](https://salicylic-acid3.hatenablog.com/entry/remap-manual)<br>

[プレートデータ](https://github.com/kushima8/Reex/tree/main/Reex67/Plate)データを公開しています。<br>
アルミプレートなど作成したい場合にお使いください。<br>

以下の部品リストを参考に欠品がないか確認をお願いします。<br>

## 部品

### キットに付属しているもの

|名称|数量|備考|
|----|:---:|----|
|PCB|2枚|右側用、左側用各1枚ずつ|
|トッププレート|2枚|右側用、左側用各1枚ずつ|
|ボトムプレート|2枚|右側用、左側用各1枚ずつ|
|M2 2.5mmスペーサー(CB-2002.5E)|4個|丸型中空|
|M2 3mmスペーサー(ARB-2003E)|10個|丸型両メネジ|
|M2 3.5mmスペーサー(ARB-2003.5E)|4個|丸型両メネジ|
|M2 4mmスペーサー(ARB-2004E)|2個|丸型両メネジ|
|M2 6mmスペーサー(ARB-2006E)|3個|丸型両メネジ|
|M2 7.5mmスペーサー(ARB-2007.5E)|10個|丸型両メネジ|
|M2 10mmスペーサー(ARB-2010E)|3個|丸型両メネジ|
|M2 4mmネジ|14本|
|M2 10mmネジ|17本|
|Kailh PCB ソケット(MX用)|69個|
|ダイオード(1N4148W)|86個|
|タクトスイッチ|2個|
|TRRSジャック(MJ-4PP-9)|2個|
|PMW3360DM-T2QU|1個|レンズ付き|
|PMW3360ブレイクアウトボード|1枚|
|トラックボールケース|2個|ローマウントとハイマウント1個ずつ|
|ステンレスミニアチュアベアリング(3×6×2.5mm)|3個|
|六角ナット(M3 厚さ2.4mm)|3個|
|(+)ナベ頭小ねじ(M3 10mm)|3個|
|コンスルーピンヘッダ(2.5mm 8PIN)|1個|
|ゴム足|8個|

### 別途、購入が必ず必要なもの
以下の部品は別途購入してください。

|名称|数量|備考|
|----|:---:|----|
|キースイッチ(Cherry MX互換)|67個|
|キーキャップ(Cherry MX互換)|67個|
|Pro Micro|2個|※|
|コンスルーピンヘッダ(2.5mm 12PIN)|4個|キットに同梱されてない場合|
|TRRSケーブル|1本|
|トラックボール(34mm)|1個|
|2Uスタビライザー(Cherry MX互換)|2個|

※動作確認しているPro Microは以下の通りになります。  
　下記以外のPro Microを使用する場合は動作しないことがあります。  
　使用する場合はご自身で調整してください。  
　Pro Micro（単体）黒基盤/青基盤  
　https://shop.yushakobo.jp/products/pro-micro?variant=42225070768359

### オプション
以下の部品はオプション品です。  
キーボードを光らせたいなどの場合のみ別途購入してください。  

|名称|数量|備考|
|----|:---:|----|
|LEDチップ(YS-SK6812MINI-E)|75個|
|OLEDモジュール|2個|
|OLED用ピンソケット|2個|

※一部画像に制作手順が似ているReex56の画像を使用しております。

## 組み立て
* 表面<br>
  
* 裏面<br>
  
* 1.ヤスリがけ
  * 製造の都合上PCBにバリが存在します。<br>
  
  * 赤丸の箇所を市販されている紙ヤスリなどで研磨してください。
* 2.Pro Microのはんだ付け
  * チップが載っている面が内側になるようにし、コンスルーピンヘッダを取り付けはんだ付けをしてください。
  * コンスルーピンヘッダには取り付け方向があるため気をつけてください。
  * [コンスルー - Self-Made Keyboards in Japan - ](https://scrapbox.io/self-made-kbds-ja/%E3%82%B3%E3%83%B3%E3%82%B9%E3%83%AB%E3%83%BC)<br>
  
* 3.ファームウェアの書き込み
 * [reex67_test.hex](https://github.com/kushima8/Reex/tree/main/Reex67/HEX/reex67_test.hex)を指定してファームウェアを書き込んでください。
* 4.センサーのはんだ付け
  * ブレイクアウトボードの既にICがはんだ付けされている⾯を表にし、4PINが2列になっている方を左側してください。
  * センサーチップの⽂字が書かれている⽅を下にして基盤にセットしたあと、裏面からはんだ付けをしてください。<br>
 
* 5.トラックボールケースの作成
  * 本キットでは基本的にロープロ版を使用します。
  * 同梱されているハイプロ版はオマケです。
  * ハイプロ版はブレイクアウトボードの上に直接置いて使えるように設計しております。
  * PMW3360ブレイクアウトボードを流用したものを作成する場合にご利用ください。
  * ケースは突起のある方が表側、その突起が2つある⽅が上、突起が1つの方が下となります。
  * 初めに上側のネジ⽳にM2 10mmネジを⼀つづ⼊れます。<br>
  
  * その後ベアリングを入れたM3 10mmネジを突起の穴に入れます。
  * 入れる方向などは下記画像を参考にしてください。
  * 設置後、六角ナットで固定してください。
  * 固定する際突起部分とベアリング部分を完全に密着せず若干ながら隙間を作るようにしてください。
  * 密着しすぎるとベアリングがうまく回らない場合があります。<br>
  
  * ケースを裏返して、M2 10mmネジを画像の三箇所に挿入してください。
  * 挿入後、M2 6mmスペーサー、M2 10mmスペーサーの順でネジに取り付けます。
  * これは玉飛び出し防止用の支柱になります。<br>
  
  
  * 一旦この状態でトラックボールを置き、干渉の確認をしてください。
  * ケース本体は3Dプリンタで製造しており、玉と支柱のクリアリングは非常にタイトな設計な為、個体差によっては玉と支柱が干渉する場合があります。
  * 干渉する場合、支柱取り付けようのネジ穴を棒ヤスリなどで外側へ拡張し、干渉しない用に加工してください。
  * 下部にトラックボールユニットを取り付ける場合は親指が触れる位置の支柱を取り除くことをオススメします。<br>
  
* 6.LEDチップのはんだ付け(オプション)
  * 高い温度ではんだ付けを行うとLED破損の可能性がありますので、約270℃に設定してはんだ付けをするようにしてください。
  * 基板裏面のL字のシルクのマークの位置にLEDの足が欠けている箇所が来るように設置し、はんだ付けを行ってください。
  * はんだ付けが完了したら一度Pro Microを取り付け、LEDが光るかどうかテストを行ってください。<br>
  
* 7.ダイオードのはんだ付け
  * PCB裏面のダイオード取り付け箇所の片側にあらかじめはんだを盛ります。<br>
  
  * その後、線が書いてある方を右(三角形の頂点の先に縦棒がある方)にセットします。
  * ダイオードをピンセットで持ちつつ、あらかじめはんだを盛った箇所をはんだごてで加熱して片側だけはんだ付けを行います。<br>
  
  * 片側のはんだ付けが完了後、もう片方もはんだ付けを行ってください。
* 8.Kailh PCB ソケット(MX用)のはんだ付け
  * PCB裏面のソケット取り付け箇所にあらかじめはんだを盛ります。<br>
  
  * 中央の穴に干渉しないようにソケットをPCB裏面に設置しはんだ付けを行ってください。<br>
  
* 9.タクトスイッチはんだ付け
  * PCB表面から取り付け、裏面からはんだ付けを行ってください。
* 10.TRRSジャックのはんだ付け
  * PCB表面から取り付け、裏面からはんだ付けを行ってください。
* 11.OLEDの取り付け(オプション)
  * OLEDモジュールとピンヘッダのハンダ付けを行ってください。
  * ピンソケットをPCB表面から取り付け、裏面からはんだ付けを行ってください。
* 12.トラックボールユニットの取り付け
  * トラックボールユニットは画像赤丸の六箇所から選択が可能です。<br>
  
  * 中央上部と中央下部の場合は9.1を、下段の場合は9.2を参考に取り付けてください。
  * 12.1 中央上部と中央下部取り付け
    * ケース下側のネジ⽳にM2 10mmネジを⼀つづ⼊れてください。
    * PCB上面にケースを配置してください。<br>
    
    * PCB裏側からコンスルーを取り付け、ネジにM2 2.5mmスペーサーを通してください。<br>
    
    * その後ブレイクアウトボードを取り付けてください。
    * ブレイクアウトボード取り付け後、M2 3.5mmスペーサーを設置してください。<br>
    
  * 12.2 下段取り付け
    * ケース下側のネジ⽳にM2 10mmネジを⼀つづ⼊れください。
    * 先程入れた下側ネジにM2 4mmスペーサーを取り付けます。
    * PCB上面にケースを配置してください。<br>
    
    * PCB裏側からコンスルーを取り付け、ネジにM2 2.5mmスペーサーを通してください。<br>
    
    * その後ブレイクアウトボードを取り付けてください。
    * ブレイクアウトボード取り付け後、M2 3.5mmスペーサーを設置してください。<br>
    
* 13.キースイッチの取り付け
  * トッププレートの穴にキースイッチを取り付けてください。<br>
  
* 14.トッププレートの取り付け
  * トッププレート上面のネジ穴からM2 10mmネジを通し、M2 3mmスペーサーで固定してください。
  * PCBとネジ穴とキースイッチが合うようにトッププレートをPCB表面に設置。
  * 設置後、PCB裏面に飛び出たネジにM2 7.5mmスペーサーを取り付けてください。<br>
  
* 15.ボトムプレートの取り付け。
  * スペーサーとボトムプレートのネジ穴の位置を合わせ、M2 4mmネジで固定してください。<br>
* 16.Pro Microの取り付け
  * Pro Microを取り付け、PCと接続しREMAPなどを用いてキースイッチの入力の確認を行ってください。
* 17.OLEDモジュールの取り付け(オプション)
  * OLEDモジュールを取り付け、PCと接続し、表示されることの確認を行ってください。
* 18.キーキャップの取り付け
  * キースイッチにキーキャップを取り付けてください。
* 19.ゴム足の取り付け
  * ボトムプレートにゴム足を取り付けください。

組み立ての手順は、以上です。

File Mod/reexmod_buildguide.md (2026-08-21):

# Reex Mod ビルドガイド

## ご購入前にお読みください

本製品をご購入いただいた時点で、下記「譲渡・再販について」の内容にご同意いただいたものとみなします。

### 譲渡・再販について

BOOTHや遊舎工房など、作者本人が販売または委託している場所以外で購入された場合、同梱品の不足や不良品への対応など、各種サポートをいたしかねます。  
そのため、以下のとおりお願いしております。

1. 本製品（完成品・未完成品・付属部品を問わず）を、ネットオークション、フリマサービス、その他の方法により第三者へ有償で譲渡することを禁止します。
2. 本項に反する行為を確認した場合、以後の販売をお断りする場合があります。

## はじめに




このたびはご購入いただきありがとうございます。  
本製品は組み立てが必要なキットです。  

作成にあたり不明点や疑問点などがありましたら、作者の[Twitterアカウント](https://twitter.com/kushima8)までご連絡ください。  
Twitter以外で連絡を頂いても対応が厳しいです。  
FF外からのリプライは通知オフにしており気づかない場合がこざいますご了承ください。  
それとDiscordのコミュニティなどで作者以外の方だけに不明点や疑問点などを質問することは非推奨です。  

写真は作成見本であり商品内容と同一ではありません。  
また仕様は予告なく変更されることがあります。  

完成品、未完成品にかかわらずヤフオク!やメルカリなどのネットオークションやフリマなどでの販売、転売は禁止しております。  
Boothや遊舎工房など作者本人が販売または委託している箇所以外で購入された場合、同梱品の不足や不良品の対応などの各種サポートが厳しいためです。  
もし発見した場合は対応します。  
ご理解のほどよろしくお願いいたします。  

各ビルドガイドの部品リストを参考に欠品がないか確認をお願いします。  
欠品や不良品などがありましたら確認したのちに対応いたします。  
ただし、海外など発送が難しい場合はこちらの指定する方法での一部返金などで対応します。  
あらかじめご了承ください。  

### ReexModの種類

ReexModはReex56とReex67に対応した拡張基板です。  
本機だけでは動作いたしません。  
必ずReex56かReex67どちらかをご用意ください。  
現在ReexModと呼ばれる拡張基盤は現在5種類位です。  
名称と詳細は下記画像を参考に確認してください。  
  
  
  
Boothなどで各種拡張基盤が一緒になった、ReexModセットを入手した場合は下記のパーツリストを参考に封入物の確認をお願いします。  
[ReexModセットパーツリスト](reexmodset_partslist.md)  
  
各種ReexModごとにビルドガイドを用意しております。  
組み立てはこちらをご確認ください。  
  
[①５キー拡張](5keymod_buildguide.md)  
[②３キー拡張](3keymod_buildguide.md)  
[③ロータリーエンコーダ拡張](rotaryencodermod_buildguide.md)  
[④１キー拡張](1keymod_buildguide.md)  
[⑤４キー拡張](4keymod_buildguide.md)  

### 用意しているファームウェアについて

* reex56mod_default.hex
  * [VIA対応(Remap)](https://github.com/kushima8/Reex/tree/main/Reex56/VIA/mod)
  * レイヤー4枚　
  * 1番レイヤーのみボールを一定動かすと3番レイヤー(マウスレイヤー)に自動遷移 
    ボールを停止して一定時間経過か、LCTRLと設定したマウスキーやスクロールキー以外を押下すると遷移前レイヤーに戻る  

* reex67mod_default.hex
  * [VIA対応(Remap)](https://github.com/kushima8/Reex/tree/main/Reex67/VIA/mod)
  * レイヤー4枚
  * 1番レイヤーのみボールを一定動かすと3番レイヤー(マウスレイヤー)に自動遷移  
    ボールを停止して一定時間経過か、LCTRLと設定したマウスキーやスクロールキー以外を押下すると遷移前レイヤーに戻る

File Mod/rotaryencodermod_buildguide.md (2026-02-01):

# ロータリーエンコーダ拡張 ビルドガイド

## はじめに
ロータリーエンコーダ拡張はReex56またはReex67の下記画像赤枠の位置へのみ取り付け可能です。  
※Reex67とReex56の差異はキースイッチ部分だけであり拡張取り付け部分は同一であるため、Reex67の画像は省略しております。



同一側でのロータリーエンコーダ拡張とトラックボール拡張の併用は出来ません。  
左右個々にロータリーエンコーダ拡張とトラックボール拡張を使用することは可能です。  
（例：○ 右側 1キー拡張＋ロータリーエンコーダ拡張、左側 3キー拡張＋トラックボール拡張  
　　：✕ 右側 ロータリーエンコーダ拡張＋トラックボール拡張　左側 拡張なし   
　　：✕ 右側 拡張なし　左側  ロータリーエンコーダ拡張＋トラックボール拡張 ）  
キー拡張との同一側での併用は可能です。  

## 部品

|名称|数量|備考|
|----|:---:|----|
|PCB|1枚|
|ロータリーエンコーダ拡張中央上部/下部用スペーサー|2個|両端穴付きバー形状のもの
|ロータリーエンコーダ拡張下段用スペーサー|1個|両端穴付きバー形状の円柱が高いもの
|ロータリーエンコーダ拡張基盤上部用スペーサー|1個|中央に凹みがある枠形状のもの
|M2 3.5mmスペーサー(ARB-2003.5E)|4個|丸型両メネジ|
|M2 4mmネジ|4本|
|M2 10mmネジ|4本|
|ダイオード(1N4148W)|2個|

### 別途、購入が必ず必要なもの
以下の部品は別途購入してください。

|名称|数量|備考|
|----|:---:|----|
|コンスルーピンヘッダ(2.5mm 8PIN)|1個|2.5mm 12PINのものなどをニッパーで加工して8PINにしてください|
|プッシュスイッチ内蔵ロータリーエンコーダ(EC11/EC12互換 or EVQWGD001)|1個|
|ノブ|1個|

## 組み立て

* 1.7Pinコンスルー加工と差し替え
  * Reex基盤本体とトラックボール用センサーボードの接続に用いている8Pinコンスルーをニッパーなどを使い7Pinコンスルーに加工します。  
  * 8Pinコンスルーの右から三番目のPinをニッパーなどで切除してください。
  
  
  * Reex基盤本体の接続部分の右から三番目のPin（F6）に7PinコンスルーのPinが無くなっている部分が来るようにセンサボードと接続するようにしてください。
  
  
* 2.ファームウェアの書き込み
  * [reex56mod_default.hex](https://github.com/kushima8/Reex/tree/main/Reex56/HEX/mod/reex56mod_default.hex) or [reex67mod_default.hex](https://github.com/kushima8/Reex/tree/main/Reex67/HEX/mod/reex56mod_default.hex)を指定してファームウェアを書き込んでください。
* 3.ダイオードのはんだ付け
  * PCB裏面のダイオード取り付け箇所の片側にあらかじめはんだを盛ります。  
  * その後、線が書いてある方を右(三角形の頂点の先に縦棒がある方)にセットします。
  * ダイオードをピンセットで持ちつつ、あらかじめはんだを盛った箇所をはんだごてで加熱して片側だけはんだ付けを行います。  
  * 片側のはんだ付けが完了後、もう片方もはんだ付けを行ってください。
* 4.ロータリーエンコーダ(EC11/EC12互換 or EVQWGD001)のはんだ付け
  * B2AとB3Bと記載のあるジャンパをショートさせてください。
  * PCB表面からロータリーエンコーダを取り付け、裏面からはんだ付けを行ってください。
  * EVQWGD001の取り付けはフックを右側に、ピンを左側にして実装してください。
  * 長方形の穴にフック側を差し込み引っ掛けてからピンをPCB側に刺すと取り付け出来ます。
  * EC11/EC12互換の場合は表面から取り付け裏面からはんだ付けを行ってください。
  * PCBの都合上固定がしにくくなっておりますので、しっかりと固定するようにはんだ付けをしてください。
* 5.本体への取り付け
  * Reex本体基盤裏側からコンスルーを取り付けます。
  * 5.1 中央上部と中央下部取り付け  
  * 画像赤枠の部分が  
  　・ロータリーエンコーダ拡張基盤上部用スペーサー  
  　・Reex本体基盤  
  　・上：ロータリーエンコーダ拡張中央上部/下部用スペーサー  
　　下：ロータリーエンコーダ拡張中央上部/下部用スペーサー  
  　・ロータリーエンコーダ拡張基盤  
  　・3.5mmmmスペーサー  
  となるようにセットし、上から10mmネジで固定してください。
  * 5..2 下段取り付け
  * 画像赤枠の部分が  
  　・ロータリーエンコーダ拡張基盤上部用スペーサー  
  　・Reex本体基盤  
  　・上：ロータリーエンコーダ拡張中央上部/下部用スペーサー  
　　下：ロータリーエンコーダ拡張下段用スペーサー  
  　・ロータリーエンコーダ拡張基盤  
  　・3.5mmmmスペーサー  
  となるようにセットし、上から10mmネジで固定してください。
  


* 6.疎通テスト
  * 取り付け後、入力可能かテストを行ってください。
  * 問題なければボトムプレートを配置し、4mmネジで固定してください。

組み立ての手順は、以上です。

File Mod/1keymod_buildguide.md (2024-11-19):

# 1キー拡張 ビルドガイド

## はじめに
1キー拡張はReex67の下記画像赤枠の位置へのみ取り付け可能です。
  



キー拡張は同一側に一つのみ増設可能です。  
ロータリーエンコーダ拡張、トラックボール拡張との同一側での併用は可能です。  
（例：○ 右側 1キー拡張＋ロータリーエンコーダ拡張、左側 3キー拡張＋トラックボール拡張
　　：✕ 右側 ロータリーエンコーダ拡張＋トラックボール拡張　左側 拡張なし 
　　：✕ 右側 拡張なし　左側  ロータリーエンコーダ拡張＋トラックボール拡張 ）

## 部品

|名称|数量|備考|
|----|:---:|----|
|PCB|1枚|
|M2 2mmスペーサー(CB-2002E)|2個|丸型中空|
|M2 7.5mmスペーサー(ARB-2007.5E)|2個|丸型両メネジ|
|M2 11mmスペーサー(ARB-20011E)|2個|丸型両メネジ|
|M2 4mmネジ|4本|
|M2 10mmネジ|4本|
|Kailh PCB ソケット(Cherry MX用)|2個|
|ダイオード(1N4148W)|3個|

### 別途、購入が必ず必要なもの
以下の部品は別途購入してください。

|名称|数量|備考|
|----|:---:|----|
|キースイッチ(Cherry MX互換)|1個|
|キーキャップ(Cherry MX互換)|1個|
|電線|3本|
|スルーホール用テストワイヤ|3本|サンハヤト スルーホール用テストワイヤー TTW-200など|

## 組み立て
※拡張基板はリバーシブルPCBとなっております。  
　使用する位置とキーキャップの大きさにより実装面が変わります。  
　適宜説明内容を読み替えてご覧ください。  
　下記赤枠はキースイッチ取り付け位置です。  
　ソケットの実装は赤枠の裏に行ってください。  

  

* 1.7Pinコンスルー加工と差し替え
  * Reex基盤本体とトラックボール用センサーボードの接続に用いている8Pinコンスルーをニッパーなどを使い7Pinコンスルーに加工します。  
  * 8Pinコンスルーの右から三番目のPinをニッパーなどで切除してください。
  
  
  * Reex基盤本体の接続部分の右から三番目のPin（F6）に7PinコンスルーのPinが無くなっている部分が来るようにセンサボードと接続するようにしてください。
  
  
* 2.ファームウェアの書き込み
  * [reex67mod_default.hex](https://github.com/kushima8/Reex/tree/main/Reex67/HEX/mod/reex56mod_default.hex)を指定してファームウェアを書き込んでください。
* 3.ダイオードのはんだ付け
  * PCB裏面のダイオード取り付け箇所の片側にあらかじめはんだを盛ります。  
  * その後、線が書いてある方を右(三角形の頂点の先に縦棒がある方)にセットします。
  * ダイオードをピンセットで持ちつつ、あらかじめはんだを盛った箇所をはんだごてで加熱して片側だけはんだ付けを行います。  
  * 片側のはんだ付けが完了後、もう片方もはんだ付けを行ってください。
* 4.Kailh PCB ソケット(Cherry MX用)のはんだ付け
  * PCB裏面のソケット取り付け箇所にあらかじめはんだを盛ります。  
  * 中央の穴に干渉しないようにソケットをPCB裏面に設置しはんだ付けを行ってください。  
* 5.本体への取り付け
  * Reex本体のボトムプレートを外します。  
  * 画像赤枠の部分に  
  　・拡張基盤  
  　・2mmスペーサー  
  　・Reex本体基盤  
  　・7.5mmスペーサー  
  となるようにセットし、上から10mmネジで固定してください。  
     
  
  
  その後拡張基盤下部に  
  　・拡張基盤  
  　・11mmスペーサー  
  となるようにセットし、上から10mmネジで固定してください。  
* 6.疎通テスト
  * 拡張基盤とReex本体基盤をテストワイヤで繋いでください。
  * TTW-200であればスルーホールに差し込むだけで接続できます。
  * 接続箇所は拡張基盤の印字とReex本体基盤の拡張取り付け部位近くにある印字が合うようにしてください。
  * Reex本体基盤の複数同じ印字がありますが、どちらに刺しても問題ありません。
  * 配線に関しては下記が画像を参考にしてください。
     
  
  * 接続後、キースイッチを取り付け入力可能かテストを行ってください。
  * 接続位置の都合上TECSEE Pudding Mediumなど通常よりロープロファイルのスイッチを使用することをおすすめします。  
  * 問題なければボトムプレートを配置し、4mmネジで固定してください。
* 7.電線のはんだ付け
  * この工程を行うと拡張基盤の取り外しが困難になります。
  * テストワイヤで接続した状態で、十分操作感などを確かめ変更の余地がないと確認後、この工程に進むようにしてください。
  * テストワイヤを外し電線と入れ替えるような形で拡張基板と本体基盤にはんだ付けを行い接続してください。

組み立ての手順は、以上です。

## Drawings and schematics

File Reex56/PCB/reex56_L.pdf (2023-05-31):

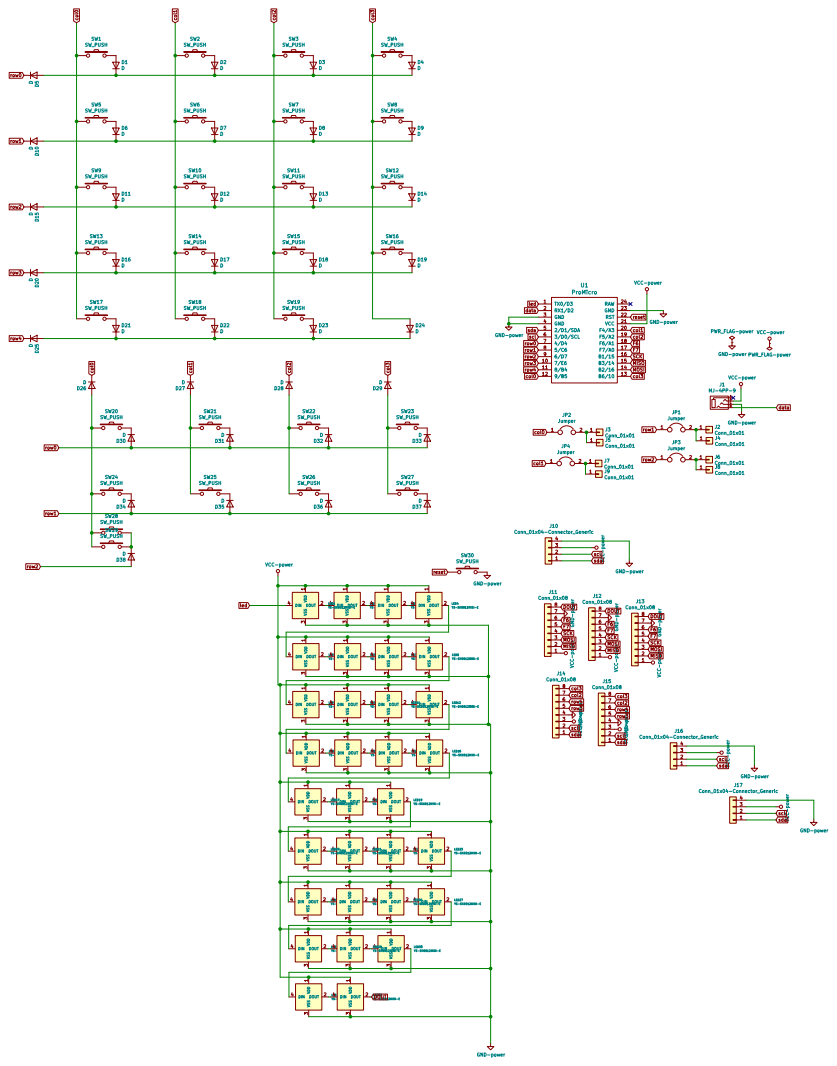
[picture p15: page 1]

VCC-power GND-power

Id: 1/1 Title: File: reex70.sch Sheet: /

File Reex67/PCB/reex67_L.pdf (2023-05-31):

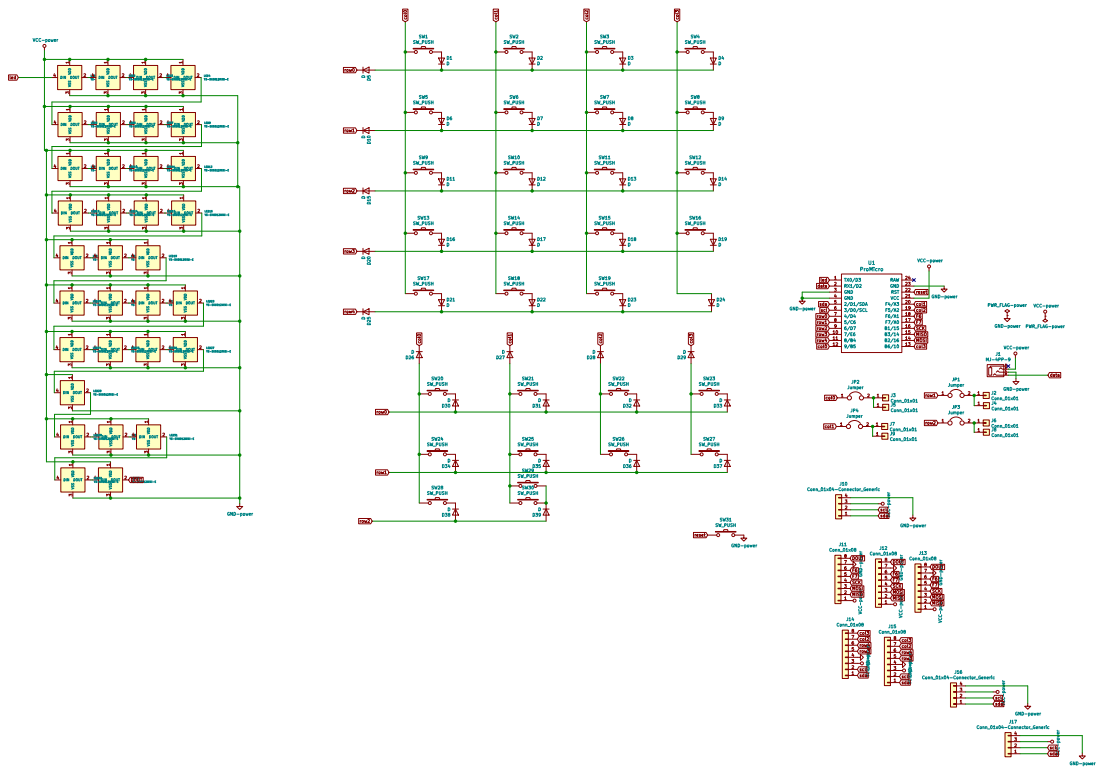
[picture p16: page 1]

SW5 SW_PUSH | | | row0 col2

SW9 SW_PUSH | SW10 SW_PUSH | SW11 SW_PUSH

SW13 SW_PUSH

scl sda
J13 Conn_01x08 VCC-power GND-power

Id: 1/1 Title: File: reex70.sch Sheet: /

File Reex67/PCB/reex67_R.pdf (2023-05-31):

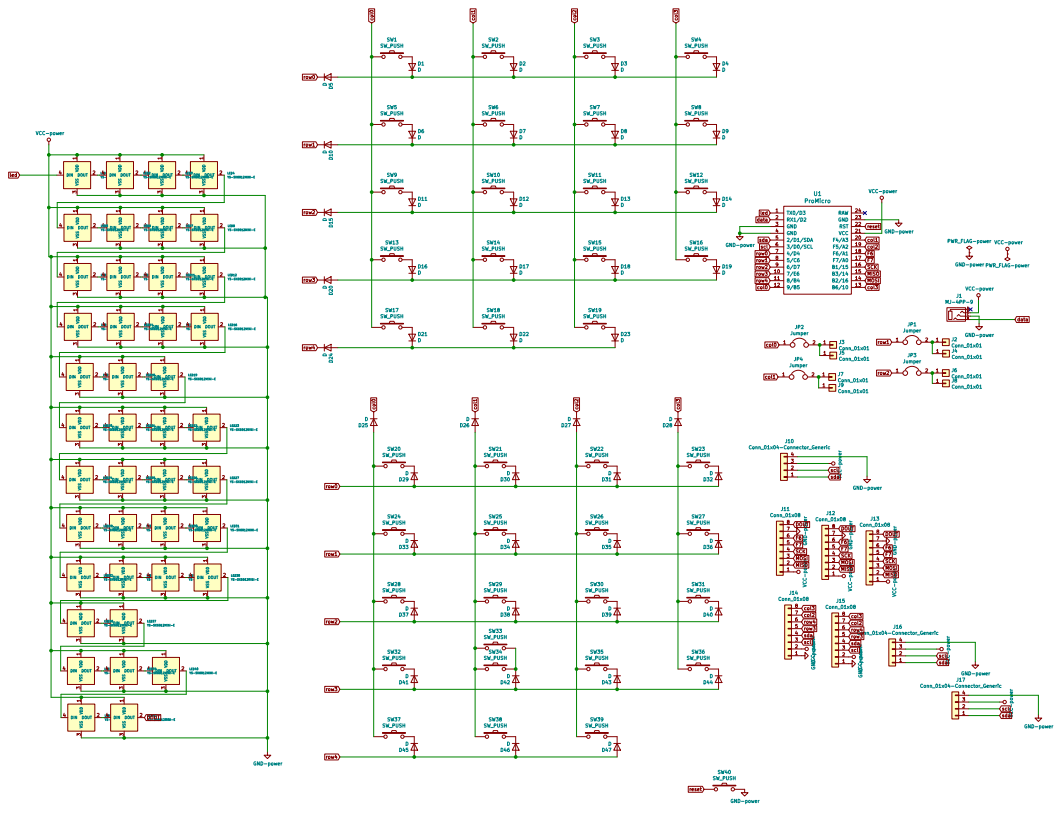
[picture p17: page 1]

scl
J13 Conn_01x08 VCC-power GND-power

SW28 SW_PUSH | SW29 SW_PUSH | | J12 Conn_01x08 SW35 SW_PUSH
SW24 SW_PUSH | SW25 SW_PUSH | SW26 SW_PUSH

Id: 1/1 Title: File: reex70.sch Sheet: /

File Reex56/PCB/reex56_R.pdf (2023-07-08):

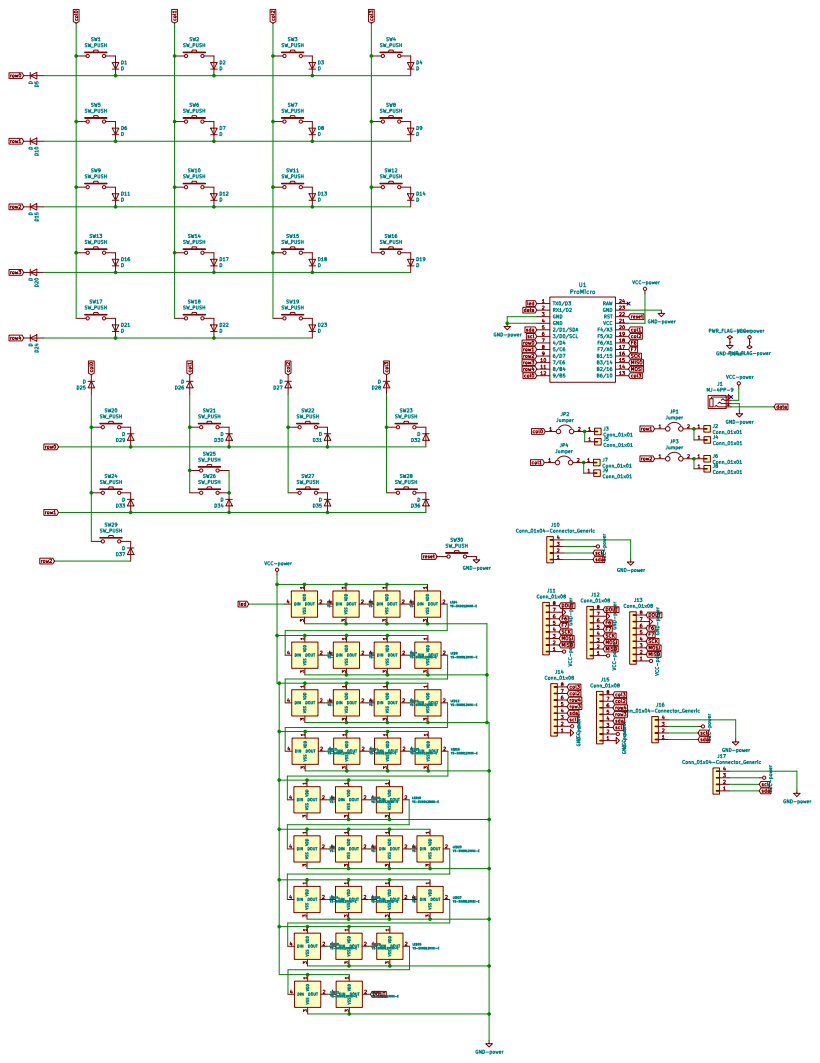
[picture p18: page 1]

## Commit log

2023-04-24 ADD Reex56&Reex67
    [reex56_b.dxf, reex56_t.dxf, reex67l_b.dxf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]
2023-05-31 ADD PCB
    [reex56.kicad_pcb, reex67.kicad_pcb]
2023-05-31 ADD BreakoutBoard
    [breakoutboard.kicad_pcb, breakoutboard.sch]
2023-06-30 add plate
    [reex_plate.dxf]
2023-11-16 0.22 対応
2026-07-12 add stl
    [reex56_case.stl, reex_2.5-3.5_spacer.stl, reex_2.5_oneside_spacer.stl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]
